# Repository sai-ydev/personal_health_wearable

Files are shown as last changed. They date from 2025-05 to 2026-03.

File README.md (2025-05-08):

# Wearable for Personal Health Monitoring
 
This is the repository for the Personal Health Monitoring Wearable. 

wearable

Here is the folder structure:
- **nRF54L15 Design Files** contains design files based on the nRF54L15 SoC. This couldn't be executed because of lack of availability.
- **BL54L15 Design Files** contains design files based on the BL54L15 module from [Ezurio](https://www.ezurio.com/product/bl54l15-series-bluetooth-le-80215-4-nfc).

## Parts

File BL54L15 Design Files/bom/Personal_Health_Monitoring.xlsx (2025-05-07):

Comment | Designator | Footprint | LCSC Part #
0 | R5 R6 R26 | RESC0603X28N | C106227
0.1uF | C1 C2 C4 C5 C7 C8 C17 C21 C23 C24 C25 C28 C31 C32 C35 C38 C42 C43 | CAPC0603X33N | C66938
1.0uF | C9 C10 C18 C19 C30 C37 | CAPC0603X33N | C76929
1.4K | R8 | RESC0603X28N | C320696
1K | R19 R21 | RESC0603X28N | C138165
2.2K | R10 R11 | RESC0603X28N | C320759
2.2nH | L1 | INDC1608X100N | C113061
2.2uF | C14 | CAPC0603X33N | C318539
2.2uH | L2 L3 | INDC2016X100N | C86093
3.9K | R18 R20 | RESC0603X28N | C171965
4.7K | R9 | RESC0603X28N | C138135
4.7UF | C20 | CAPC0603X33N | C335103
5.1K | R12 R13 | RESC0603X28N | C274341
10K | R4 R7 R14 | RESC0603X28N | C144833
10uF | C3 C11 C12 C13 C15 C16 C27 C29 C33 C36 C39 C22 | 402 | C15525
27K | R22 R23 | RESC0603X28N | C273283
32.768kHz | Y3 | CRYSTAL-SMD-3.2X1.5MM | C48615
47K | R3 | RESC0603X28N | C138097
100 | R1 | RESC0603X28N | C106229
100K | R16 R17 | RESC0603X28N | C106224
100UF | C26 | CAPC2012X145N | C141660
150 | R15 | RESC0603X28N | C319851
453-00001R | U3 | XCVR_453-00001R | C9900177187
470K | R2 | RESC0603X28N | C138098
470nF | C40 C41 | CAPC0603X33N | C85926
BLUE | D2 | LED-0603 | C94740
DNP | R24 R25 | RESC0603X28N | DNP
Debug Connector | J1 | 2X5-SMD-UNSHROUDED_DNP_NO_PASTE | C448647
EAST1616RGYA0 | LED1 | EAST1616RGYA0 | C19171339
EYESPI | X1 | ADAFRUIT_DISPLAY_EYE_SPI_DISPLAY_BOTCONTACT | C2856802
ICS-43434 | MK1 | MIC_ICS-43434 | C5656610
INTERFACE-CP2102-GMR(QFN28) | U7 | QFN28G_0.5-5X5MM | C6568
JS202011JCQN | S1 | SW_JS202011JCQN | C221665
KMR221GLFS | S2 | TACTILE_SWITCH_SMD_4.6X2.8MM | C72443
LMV358MUTAG | U2 | SON40P180X120X55-8N | C891366
LSM6DS3TR-C | U6 | LGA-14-2.5X3MM | C967633
MAX30102EFD+T | U4 | XDCR_MAX30101EFD+ | C6454833
MLX90632SLD-BCB-000-SP | U5 | XDCR_MLX90632SLD-BCB-000-SP | C7541116
NPM1300-QEAA-R | IC1 | QFN50P500X500X90-33N | C7501206
Qwiic Right Angle | J5 | JST04_1MM_RA | C160404
RV-3028-C7 | U1 | IC_RV-3028-C7-32.768KHZ-1PPM-TA-QC | C3019759
TEST-POINT3 | -0.4V -3.3V 1.2VREF 1.8V 1.8V_SW 3.3V 3.3V_SW ADC1 ADC2 VSYS V_BATT V_USB | PAD.03X.03 | DNP
TLR377GYZ-E2 | IC2 IC3 IC4 IC5 | BGA6C30P3X2_88X58X33 | C25814939
TPS60403DBVR | U10 | SOT95P280X145-5N | C11338
TYPE-C-31-M-12 | J2 | HRO_TYPE-C-31-M-12 | C165948
WA-SMSI_9774XXX243_9774045243R | MP1 MP2 MP3 MP4 | WA-SMSI_9774045243 | C9900153365

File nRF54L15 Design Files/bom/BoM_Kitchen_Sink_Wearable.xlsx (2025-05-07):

Part | Price
Glucometer Test Strip Connector | 0.13
Bluetooth Module | 3.99
LSM6DS3TR IMU | 3.82
Microphone | 3.12
MAX30102 Heart Rate/SPO2 sensor | 13.39
MLX90632 Temperature Sensor | 13.75
1.47" Display | 17.5

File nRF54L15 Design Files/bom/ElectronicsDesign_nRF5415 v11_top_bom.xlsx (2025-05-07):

Comment | Designator | Footprint | LCSC Part #
0 | R5 R6 R26 | RESC0603X28N | C106227
0.1uF | C1 C2 C4 C5 C7 C8 C17 C18 C21 C23 C24 C25 C28 C31 C32 C34 C35 C37 C38 C43 | CAPC0603X33N | C66938
0.3pF | C48 | CAPC0603X33N | C76927
0.5pF | C47 | CAPC0603X33N | C161292
1.0UF | C9 C10 C19 C30 | CAPC0603X33N | C76929
1.4K | R8 | RESC0603X28N | C320696
1.5pF | C50 | CAPC0603X33N | C85897
1K | R19 R21 R24 | RESC0603X28N | C138165
1nH | L5 L6 | INDC0603X33N | C86099
2.0pF | C49 | CAPC0603X33N | C88875
2.2K | R10 R11 | RESC0603X28N | C320759
2.2nH | L1 | INDC1608X100N | C113061
2.2uF | C14 C42 C44 | CAPC0603X33N | C318539
2.2uH | L2 L3 | INDC2016X100N | C86093
2.7nH | L7 | INDC0603X33N | C86109
3.5nH | L8 L9 | INDC0603X33N | C206424
3.9K | R18 R20 | RESC0603X28N | C171965
3.9pF | C6 | CAPC0603X33N | C76926
4.7K | R9 | RESC0603X28N | C138135
4.7UF | C20 | CAPC0603X33N | C335103
5.1K | R12 R13 | RESC0603X28N | C274341
10K | R4 R7 R14 | RESC0603X28N | C144833
10nF | C45 C46 | CAPC0603X33N | C85930
10uF | C3 C11 C12 C13 C15 C16 C22 C27 C29 C33 C36 C39 | 0402-TIGHT | C15525
27K | R22 R23 | RESC0603X28N | C158653
47K | R3 | RESC0603X28N | C138097
100 | R1 | RESC0603X28N | C106229
100K | R16 R17 | RESC0603X28N | C106224
100UF | C26 | CAPC2012X145N | C141660
120O | FB1 | BEADC0603X33N | C88958
150 | R15 | RESC0603X28N | C319851
470K | R2 | RESC0603X28N | C138098
470nF | C40 C41 | CAPC0603X33N | C85926
BLUE | D2 | LED-0603 | C94740
Debug Connector | J1 | 2X5-SMD-UNSHROUDED_DNP_NO_PASTE | C448647
EAST1616RGYA0 | LED1 | EAST1616RGYA0 | C19171339
ECS-320-CDX-2291 | Y1 | XTAL_ECS-320-CDX-2291 | C187794
EYESPI | X1 | ADAFRUIT_DISPLAY_EYE_SPI_DISPLAY_BOTCONTACT | C2856802
INTERFACE-CP2102-GMR(QFN28) | U7 | QFN28G_0.5-5X5MM | C6568
JS202011JCQN | S1 | SW_JS202011JCQN | C221665
KMR221GLFS | S2 | TACTILE_SWITCH_SMD_4.6X2.8MM | C72443
LMV358MUTAG | U2 | SON40P180X120X55-8N | C891366
LQM18PN4R7MFRL | L4 | INDC1608X95N | LQM18PN4R7MFRL
LSM6DS3TR-C | U6 | LGA-14-2.5X3MM | C967633
MAX30102EFD+T | U4 | XDCR_MAX30101EFD+ | C6454833
MLX90632SLD-BCB-000-SP | U5 | XDCR_MLX90632SLD-BCB-000-SP | C7541116
NPM1300-QEAA-R | IC1 | QFN50P500X500X90-33N | C7501206
NRF54L15-QFAA-R | U8 | QFN40P600X600X90-49N | C42458750
Qwiic Right Angle | J5 | JST04_1MM_RA | C160404
RV-3028-C7 | U1 | IC_RV-3028-C7-32.768KHZ-1PPM-TA-QC | C3019759
TEST-POINT3 | -0.4V -3.3V 1.2VREF 1.8V 3.3V ADC1 ADC2 VSYS V_BATT V_USB | PAD.03X.03 | DNP
TLR377GYZ-E2 | IC2 IC3 IC4 IC5 | BGA6C30P3X2_88X58X33 | C25814939
TPS60403DBVR | U10 | SOT95P280X145-5N | C11338
TYPE-C-31-M-12 | J2 | HRO_TYPE-C-31-M-12 | C165948
WA-SMSI_9774XXX243_9774045243R | MP1 MP2 MP3 MP4 | WA-SMSI_9774045243 | C9900153365
YC0009AA | E1 | XCVR_YC0009AA | C3292972

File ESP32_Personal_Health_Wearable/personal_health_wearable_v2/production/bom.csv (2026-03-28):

Designator | Footprint | Quantity | Value | LCSC Part #
C1 | 0402 | 1 | 22uF | C105226
C10, C11, C12, C13, C2, C25, C3, C4, C5, C6 | 0402 | 10 | 0.1uF | C1525
C14, C15, C16, C17, C18, C19, C20, C21, C22, C23, C24, C26, C29, C31, C33 | 0402 | 15 | 1.0uF | C361059
C27, C28 | 0402 | 2 | 2.2uF | C159814
C30, C7, C8, C9 | 0402 | 4 | 10uF | C15525
C32 | 0402 | 1 | 470nF | C47339
CN1 | FPC-SMD_30P-P0.50_FH12A-30S-0.5SH | 1 | ~ | C3036214
D1 | 0402 | 1 | Red | C74341
D2 | D_SOD-523 | 1 | 350mA | C154768
J1 | HRO_TYPE-C-31-M-12 | 1 | TYPE-C-31-M-12 | C165948
J4 | JST_1x02_P2.0mm_Horizontal_SMD | 1 | JST_2mm_LiPo | C295747
L1 | 0402 | 1 | 2.2nH | C27122
L2 | IND_LQH3NPN2R2MJRL | 1 | LQH3NPN2R2MJRL | C341775
R1, R13, R14, R2 | 0402 | 4 | 10k | C25531
R10 | 0402 | 1 | 0 | C17168
R11 | 0402 | 1 | 1.1K | C25860
R12 | 0402 | 1 | 590 | C159007
R15 | 0402 | 1 | 0.01 | C346478
R3, R6 | 0402 | 2 | 100 | C25076
R4, R5 | 0402 | 2 | 5.1k | C25905
SW1, SW2 | Push_SMD_4.6x2.8mm_h1.9mm | 2 | SMD_4.6x2.8mm_h1.9mm | C99271
U1 | ESP32-C6-MINI-1 | 1 | ESP32-C6-MINI-1 | C5736265
U3 | Texas_DRC0010J_ThermalVias | 1 | TPS63001 | C28060
U4, U6 | SON50P400X400X80-15N | 2 | LMP91000SDE_NOPB | C181364
U5 | TSSOP-10_3x3mm_P0.5mm | 1 | ADS1114IDGS | C174291
U7 | VQFN-16-1EP_3x3mm_P0.5mm_EP1.6x1.6mm | 1 | BQ24075RGT | C15464
U8 | Texas_S-PDSO-N12 | 1 | BQ27441DRZR-G1A | C473397

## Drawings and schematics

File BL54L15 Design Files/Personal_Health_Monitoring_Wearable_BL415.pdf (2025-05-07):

A

1 | 2 | 3 | 4 | 5 | 6 | 7 | 8

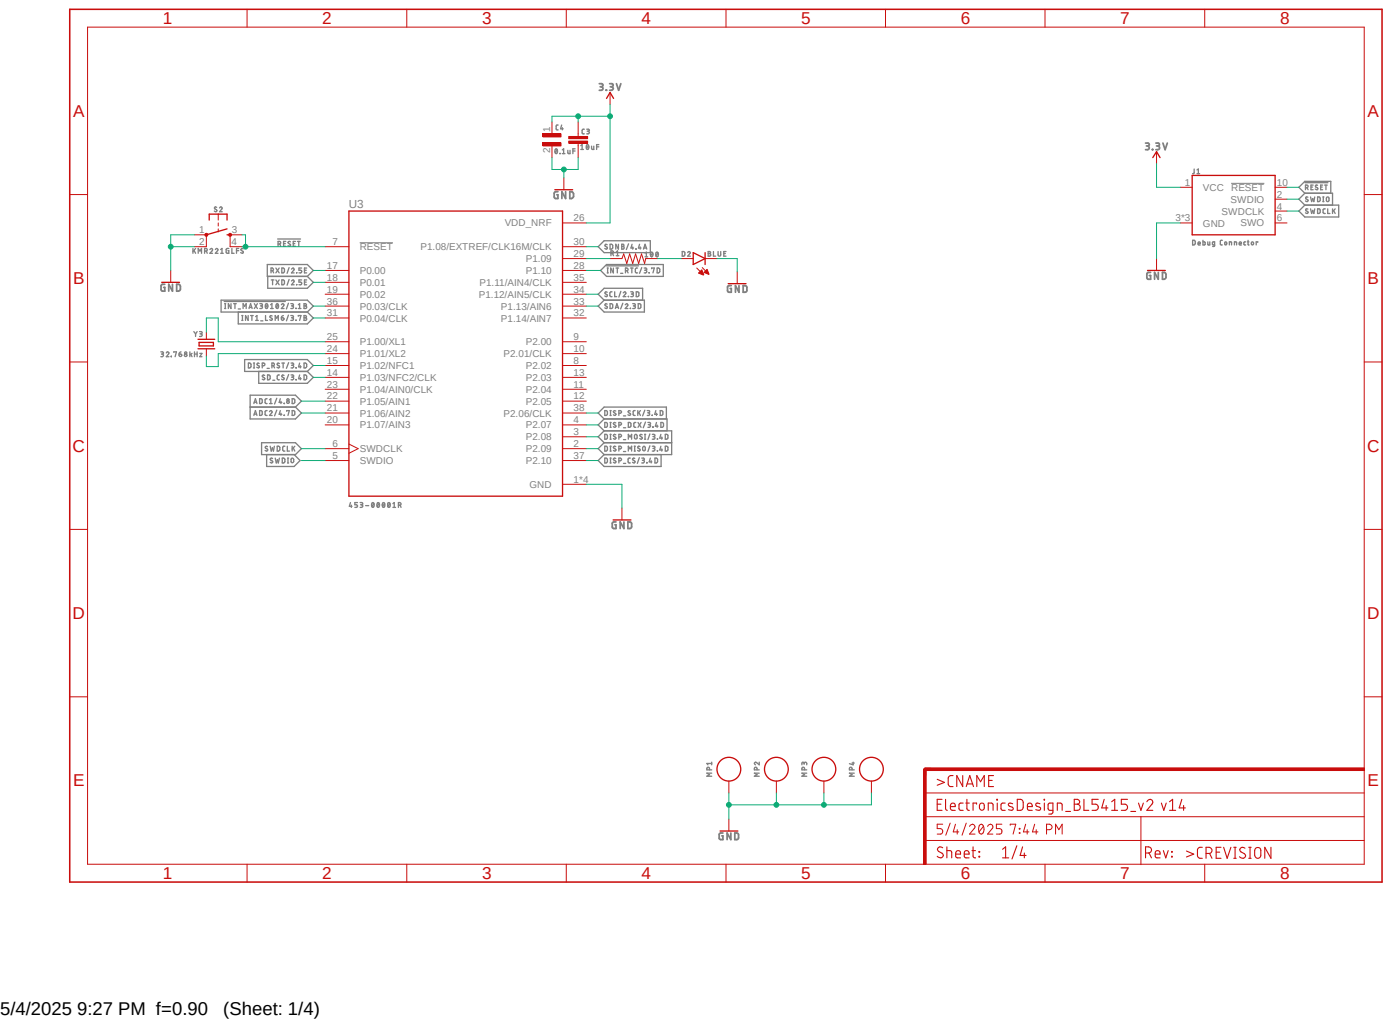
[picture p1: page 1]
5/4/2025 9:27 PM f=0.90 (Sheet: 1/4); VCC 1; GND 3*3; RESET; 10 SWO; 6 SWDCLK; 4 SWDIO; VDD_NRF; 26 SWDIO 5; SWDCLK 6; RESET 7; GND; 1*4 P2.01/CLK; 12 P2.06/CLK; P1.02/NFC1 15; P1.03/NFC2/CLK 14; P1.04/AIN0/CLK 23; P1.05/AIN1 22; P1.06/AIN2 21; P1.07/AIN3 20; P1.08/EXTREF/CLK16M/CLK; P0.03/CLK 36; P0.04/CLK 31; P1.14/AIN7; 32 P1.13/AIN6; 33 P1.12/AIN5/CLK; 34 P1.11/AIN4/CLK

A

A

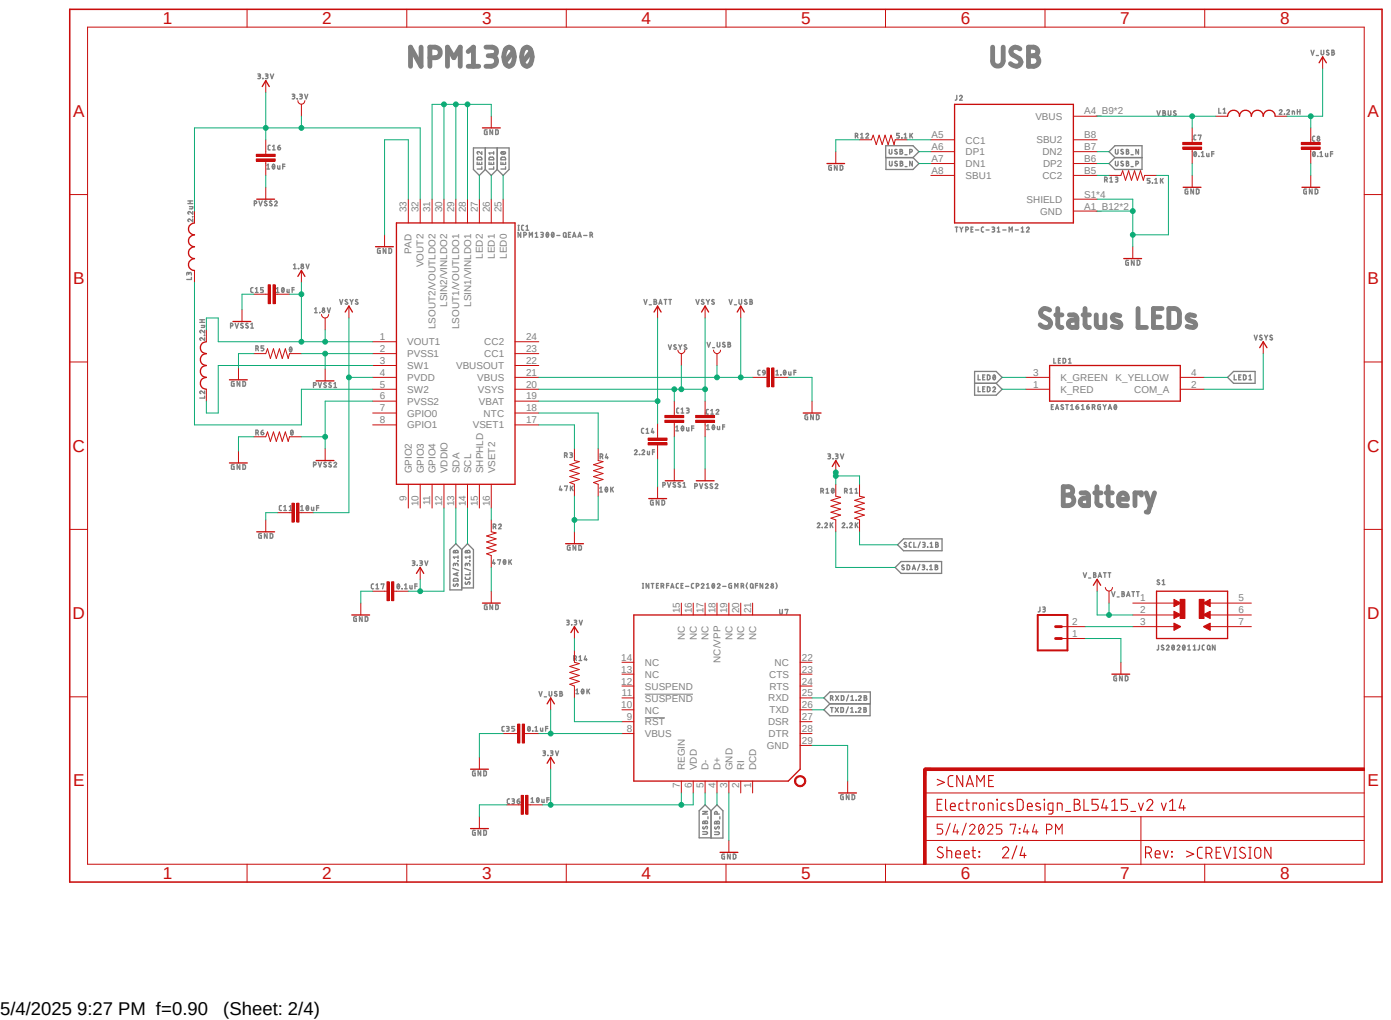
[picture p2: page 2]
5/4/2025 9:27 PM f=0.90 (Sheet: 2/4); VOUT1 1; PVSS1 2; PVDD 4; PVSS2 6; GPIO0 7; GPIO1 8; GPIO²; SBU1 A8; SHIELD; S1*4 GND; A1_B12*2 VBUS; B5 SBU2; B7 K_RED 1; COM_A; 2 K_GREEN 3; K_YELLOW; 7 DCD; 1 RI 2 GND; 4 D- 5 VDD; 6 REGIN

9 GPIO3 10 GPIO4 11 VDDIO 12 SDA 13 SCL 14 SHPHLD 15 VSET2 16 CC2 24 CC1 23 VBUSOUT 22 VBUS 21 VSYS 20 VBAT 19 NTC 18 VSET1 17 PAD 33 VOUT2 32 LSOUT2/VOUTLDO2 31 LSIN2/VINLDO2 30 LSOUT1/VOUTLDO1 29 LSIN1/VINLDO1 28 LED2 27 LED1 26 LED0 25

7 VBUS 8 RST 9 NC 10 SUSPEND 11 SUSPEND 12 NC 13 NC 14 NC 15 NC 16 NC 17 NC/VPP 18 NC 19 NC 20 NC 21 NC 22 CTS 23 RTS 24 RXD 25 TXD 26 DSR 27 DTR 28 GND 29

A

A

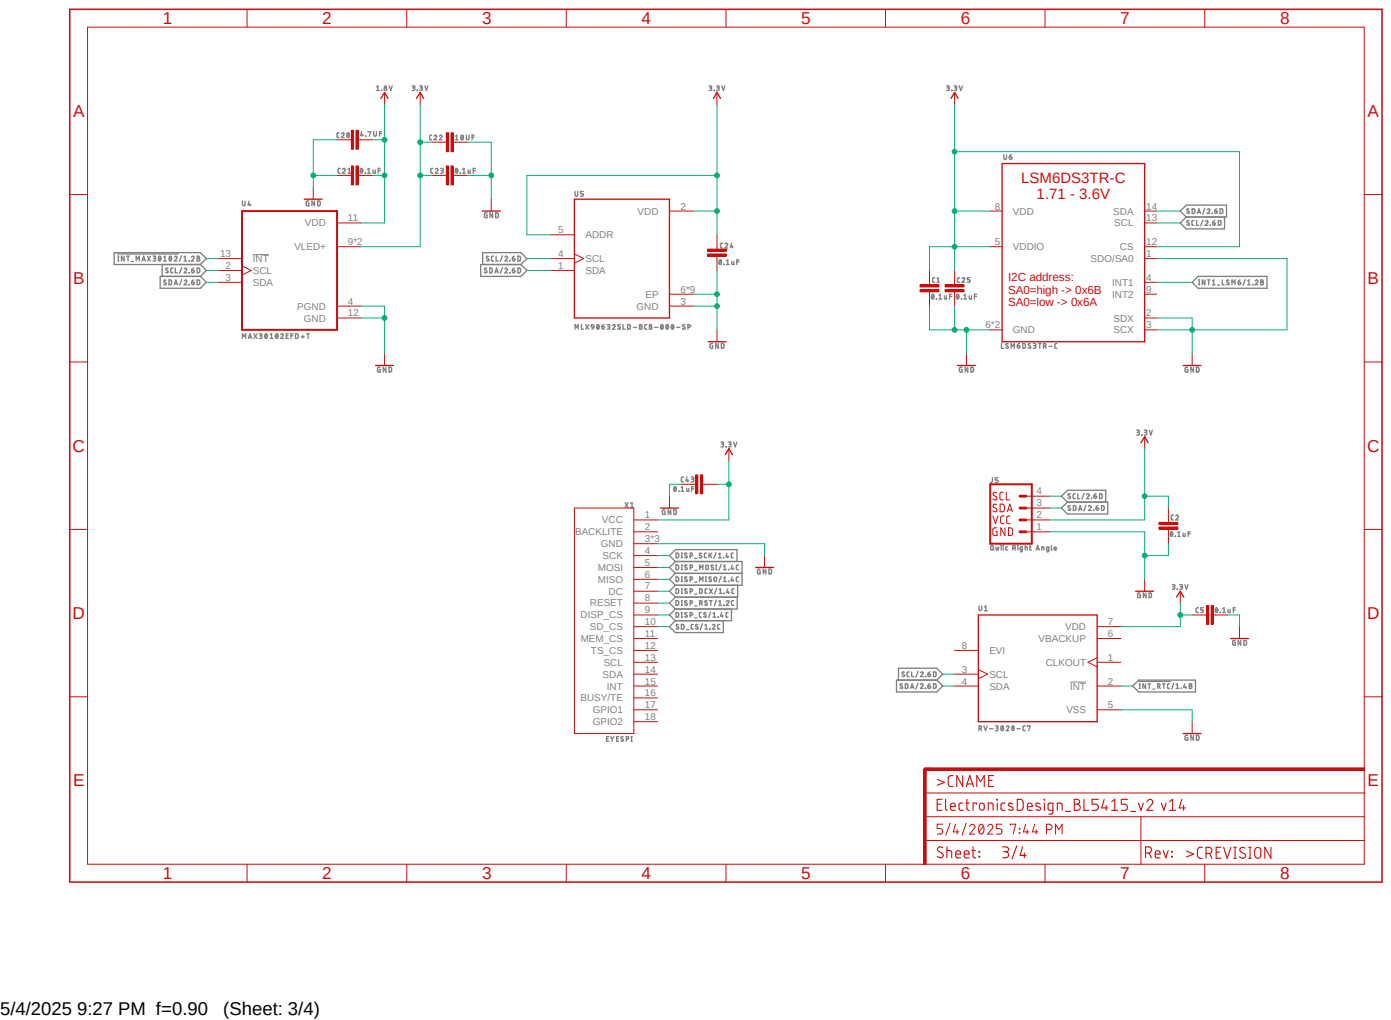
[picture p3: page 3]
5/4/2025 9:27 PM f=0.90 (Sheet: 3/4); INT 13; SCL 2; SDA 3; VDD; 11 VLED+; 9*2 PGND; 4 GND; SDA 1; 2 GND; 3 SCL 4; ADDR 5; VDD 8; VDDIO 5; INT1; INT2; 9 GND 6*2; SDA; 14 SDO/SA0; 12 SCL; 13 SDX; 2 SCX; 3 BACKLITE; 2 BUSY/TE; 7 DISP_CS; 9 GND; 3*3 GPIO1; 17 GPIO2; INT; 15 MEM_CS; 11 MISO; 6 MOSI; 5 RESET; 8 SCK; 4 SCL; 13 SDA; 12 VCC; 7 VSS; 5 CLKOUT; 2 EVI 8; SCL 3; SDA 4; VBACKUP; LSM6DS3TR-C 1.71 - 3.6V; I2C address: SA0=high -> 0x6B SA0=low -> 0x6A

A

1 | 2 | 3 | 4 | 5 | 6 | 7 | 8

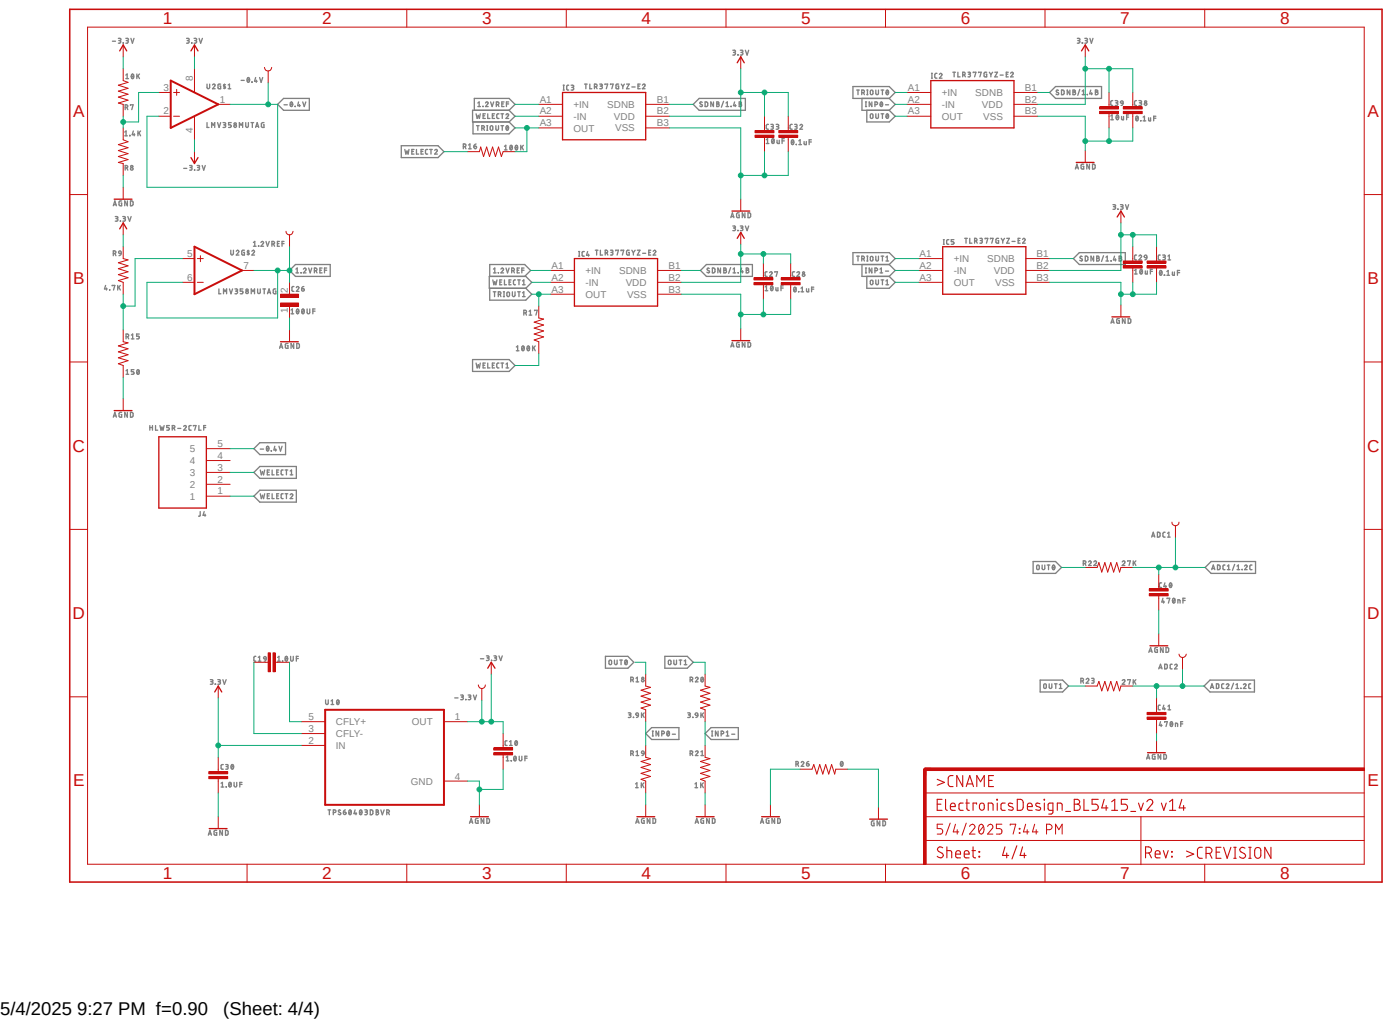
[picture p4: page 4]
5/4/2025 9:27 PM f=0.90 (Sheet: 4/4); CFLY+ 5; CFLY- 3; OUT; 1 GND; OUT A3; SDNB; B1 VDD; B2 VSS

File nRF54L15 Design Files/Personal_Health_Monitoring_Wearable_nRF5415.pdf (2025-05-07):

A

1 | 2 | 3 | 4 | 5 | 6 | 7 | 8

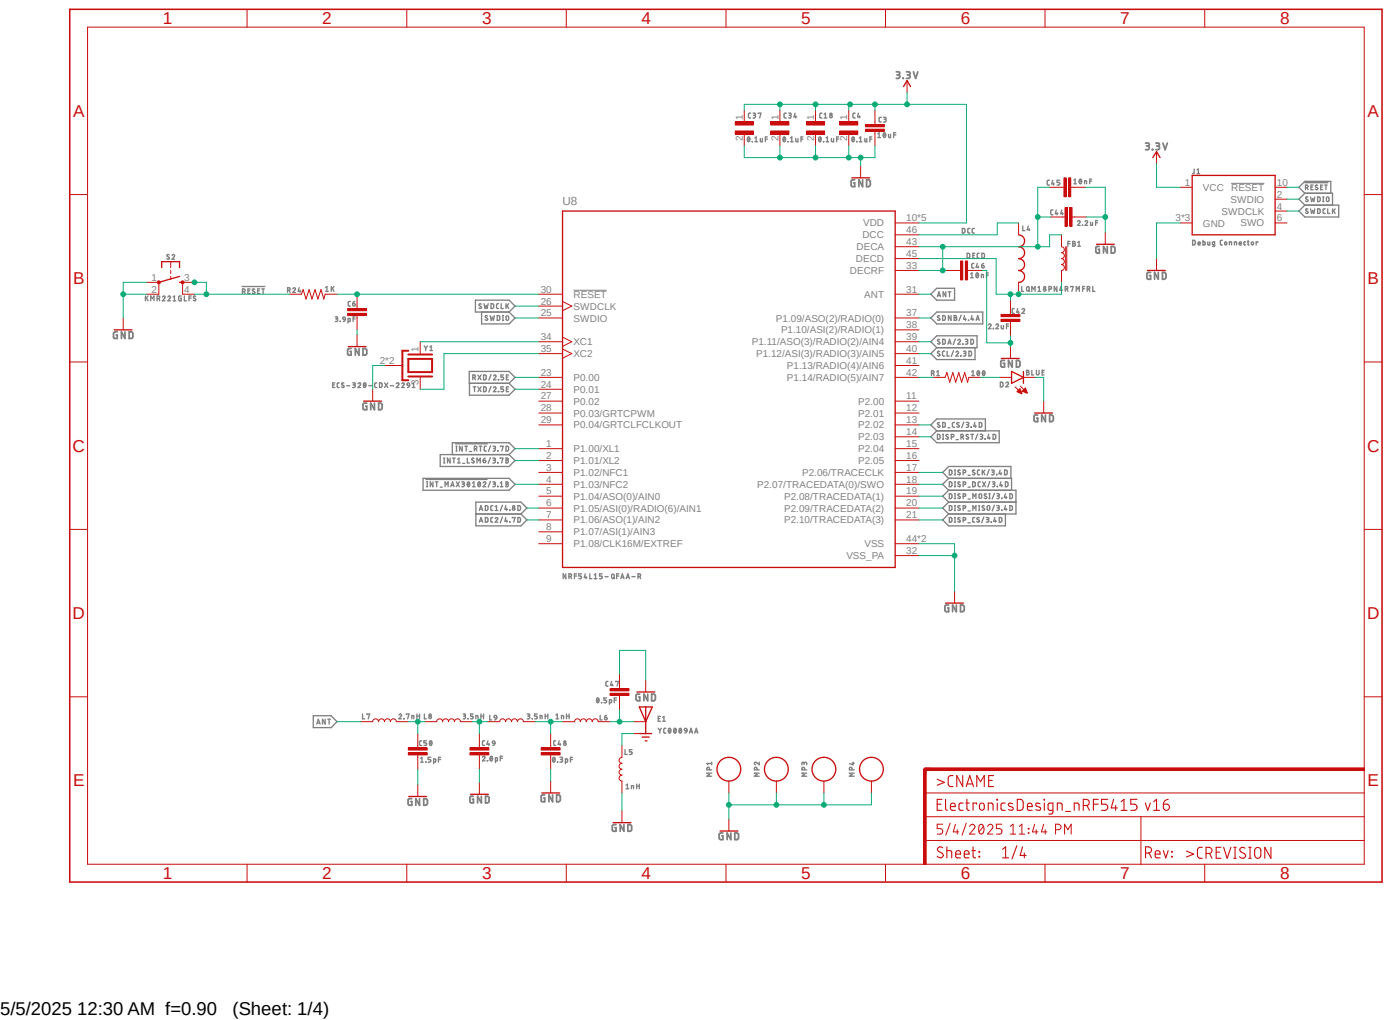
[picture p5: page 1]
5/5/2025 12:30 AM f=0.90 (Sheet: 1/4); VCC 1; GND 3*3; RESET; 10 SWO; 6 SWDCLK; 4 SWDIO; DCC; 46 DECA; 43 DECD; 45 DECRF; 33 VDD; 10*5 RESET 30; SWDCLK 26; P0.03/GRTCPWM 28; P0.04/GRTCLFCLKOUT 29; P1.02/NFC1 3; P1.03/NFC2 4; P1.04/ASO(0)/AIN0 5; P1.05/ASI(0)/RADIO(6)/AIN1 6; P1.06/ASO(1)/AIN2 7; P1.07/ASI(1)/AIN3 8; P1.08/CLK16M/EXTREF 9; P1.09/ASO(2)/RADIO(0); 37 P1.10/ASI(2)/RADIO(1); 38 ANT; 31 P1.11/ASO(3)/RADIO(2)/AIN4; 39 P1.12/ASI(3)/RADIO(3)/AIN5; 40 P1.13/RADIO(4)/AIN6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

A

A

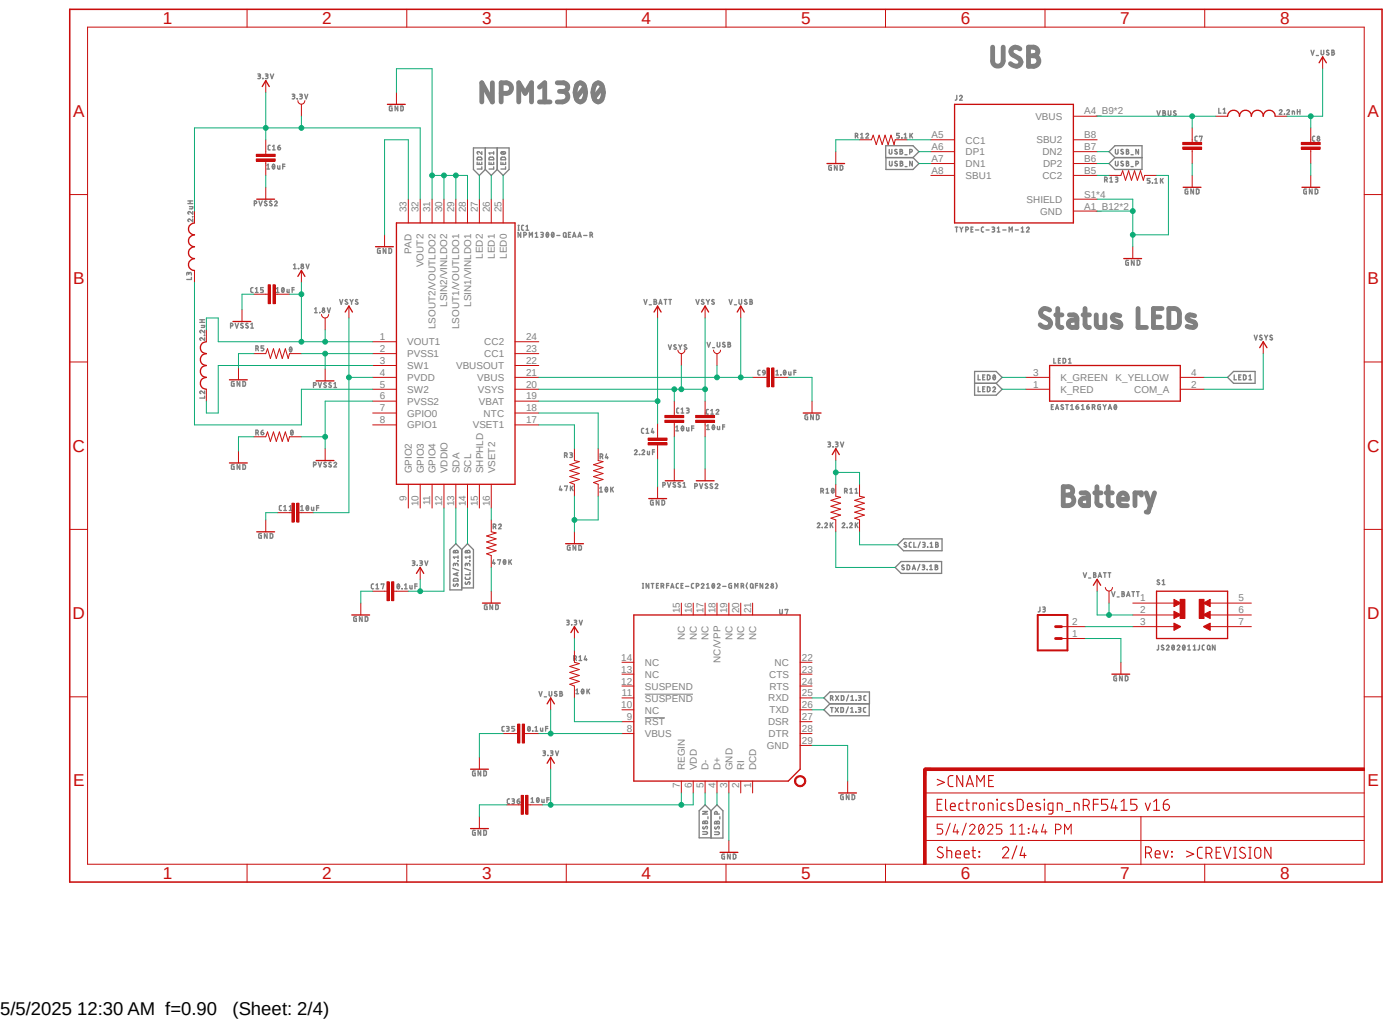
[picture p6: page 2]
5/5/2025 12:30 AM f=0.90 (Sheet: 2/4); VOUT1 1; PVSS1 2; PVDD 4; PVSS2 6; GPIO0 7; GPIO1 8; GPIO²; SBU1 A8; SHIELD; S1*4 GND; A1_B12*2 VBUS; B5 SBU2; B7 K_RED 1; COM_A; 2 K_GREEN 3; K_YELLOW; 7 DCD; 1 RI 2 GND; 4 D- 5 VDD; 6 REGIN

9 GPIO3 10 GPIO4 11 VDDIO 12 SDA 13 SCL 14 SHPHLD 15 VSET2 16 CC2 24 CC1 23 VBUSOUT 22 VBUS 21 VSYS 20 VBAT 19 NTC 18 VSET1 17 PAD 33 VOUT2 32 LSOUT2/VOUTLDO2 31 LSIN2/VINLDO2 30 LSOUT1/VOUTLDO1 29 LSIN1/VINLDO1 28 LED2 27 LED1 26 LED0 25

7 VBUS 8 RST 9 NC 10 SUSPEND 11 SUSPEND 12 NC 13 NC 14 NC 15 NC 16 NC 17 NC/VPP 18 NC 19 NC 20 NC 21 NC 22 CTS 23 RTS 24 RXD 25 TXD 26 DSR 27 DTR 28 GND 29

A

A

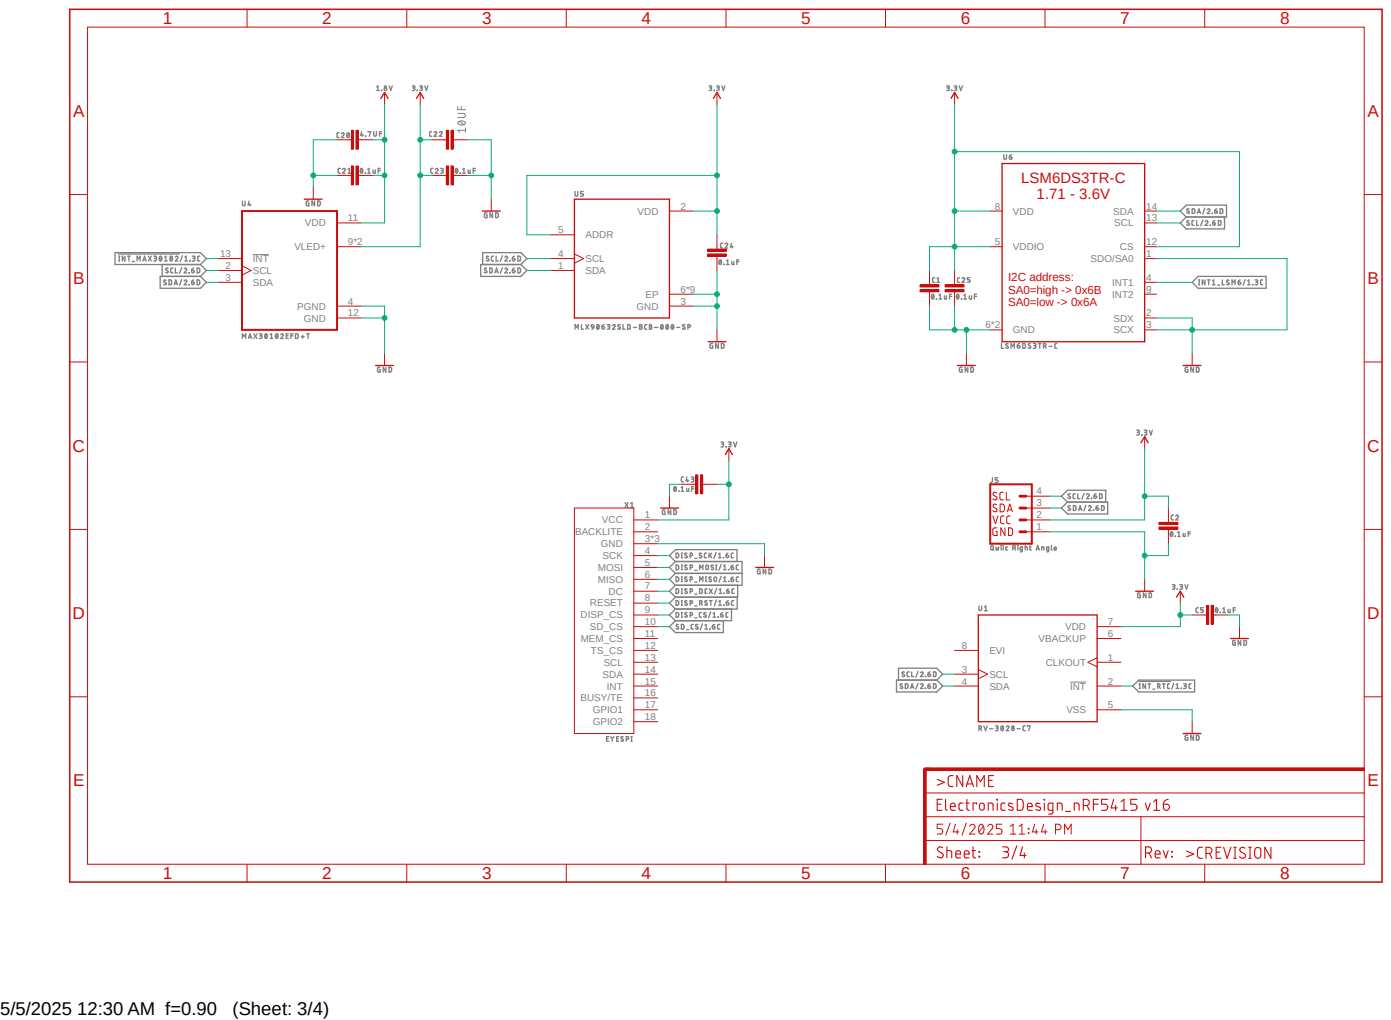
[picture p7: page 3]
5/5/2025 12:30 AM f=0.90 (Sheet: 3/4); INT 13; SCL 2; SDA 3; VDD; 11 VLED+; 9*2 PGND; 4 GND; SDA 1; 2 GND; 3 SCL 4; ADDR 5; VDD 8; VDDIO 5; INT1; INT2; 9 GND 6*2; SDA; 14 SDO/SA0; 12 SCL; 13 SDX; 2 SCX; 3 BACKLITE; 2 BUSY/TE; 7 DISP_CS; 9 GND; 3*3 GPIO1; 17 GPIO2; INT; 15 MEM_CS; 11 MISO; 6 MOSI; 5 RESET; 8 SCK; 4 SCL; 13 SDA; 12 VCC; 7 VSS; 5 CLKOUT; 2 EVI 8; SCL 3; SDA 4; VBACKUP; LSM6DS3TR-C 1.71 - 3.6V; I2C address: SA0=high -> 0x6B SA0=low -> 0x6A

A

1 | 2 | 3 | 4 | 5 | 6 | 7 | 8

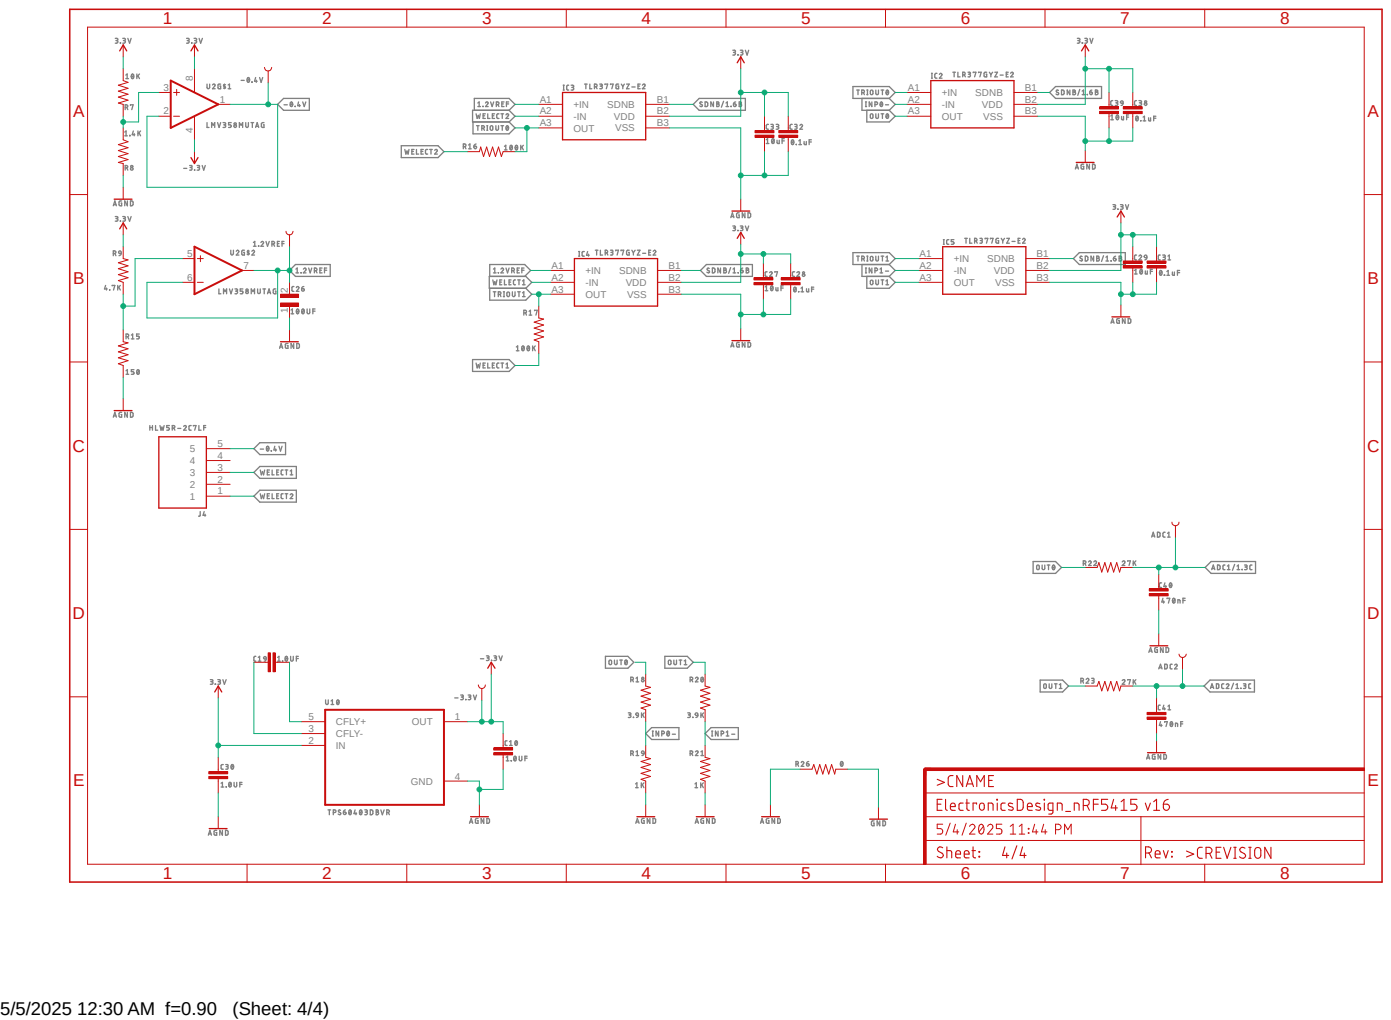
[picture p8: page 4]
5/5/2025 12:30 AM f=0.90 (Sheet: 4/4); CFLY+ 5; CFLY- 3; OUT; 1 GND; OUT A3; SDNB; B1 VDD; B2 VSS

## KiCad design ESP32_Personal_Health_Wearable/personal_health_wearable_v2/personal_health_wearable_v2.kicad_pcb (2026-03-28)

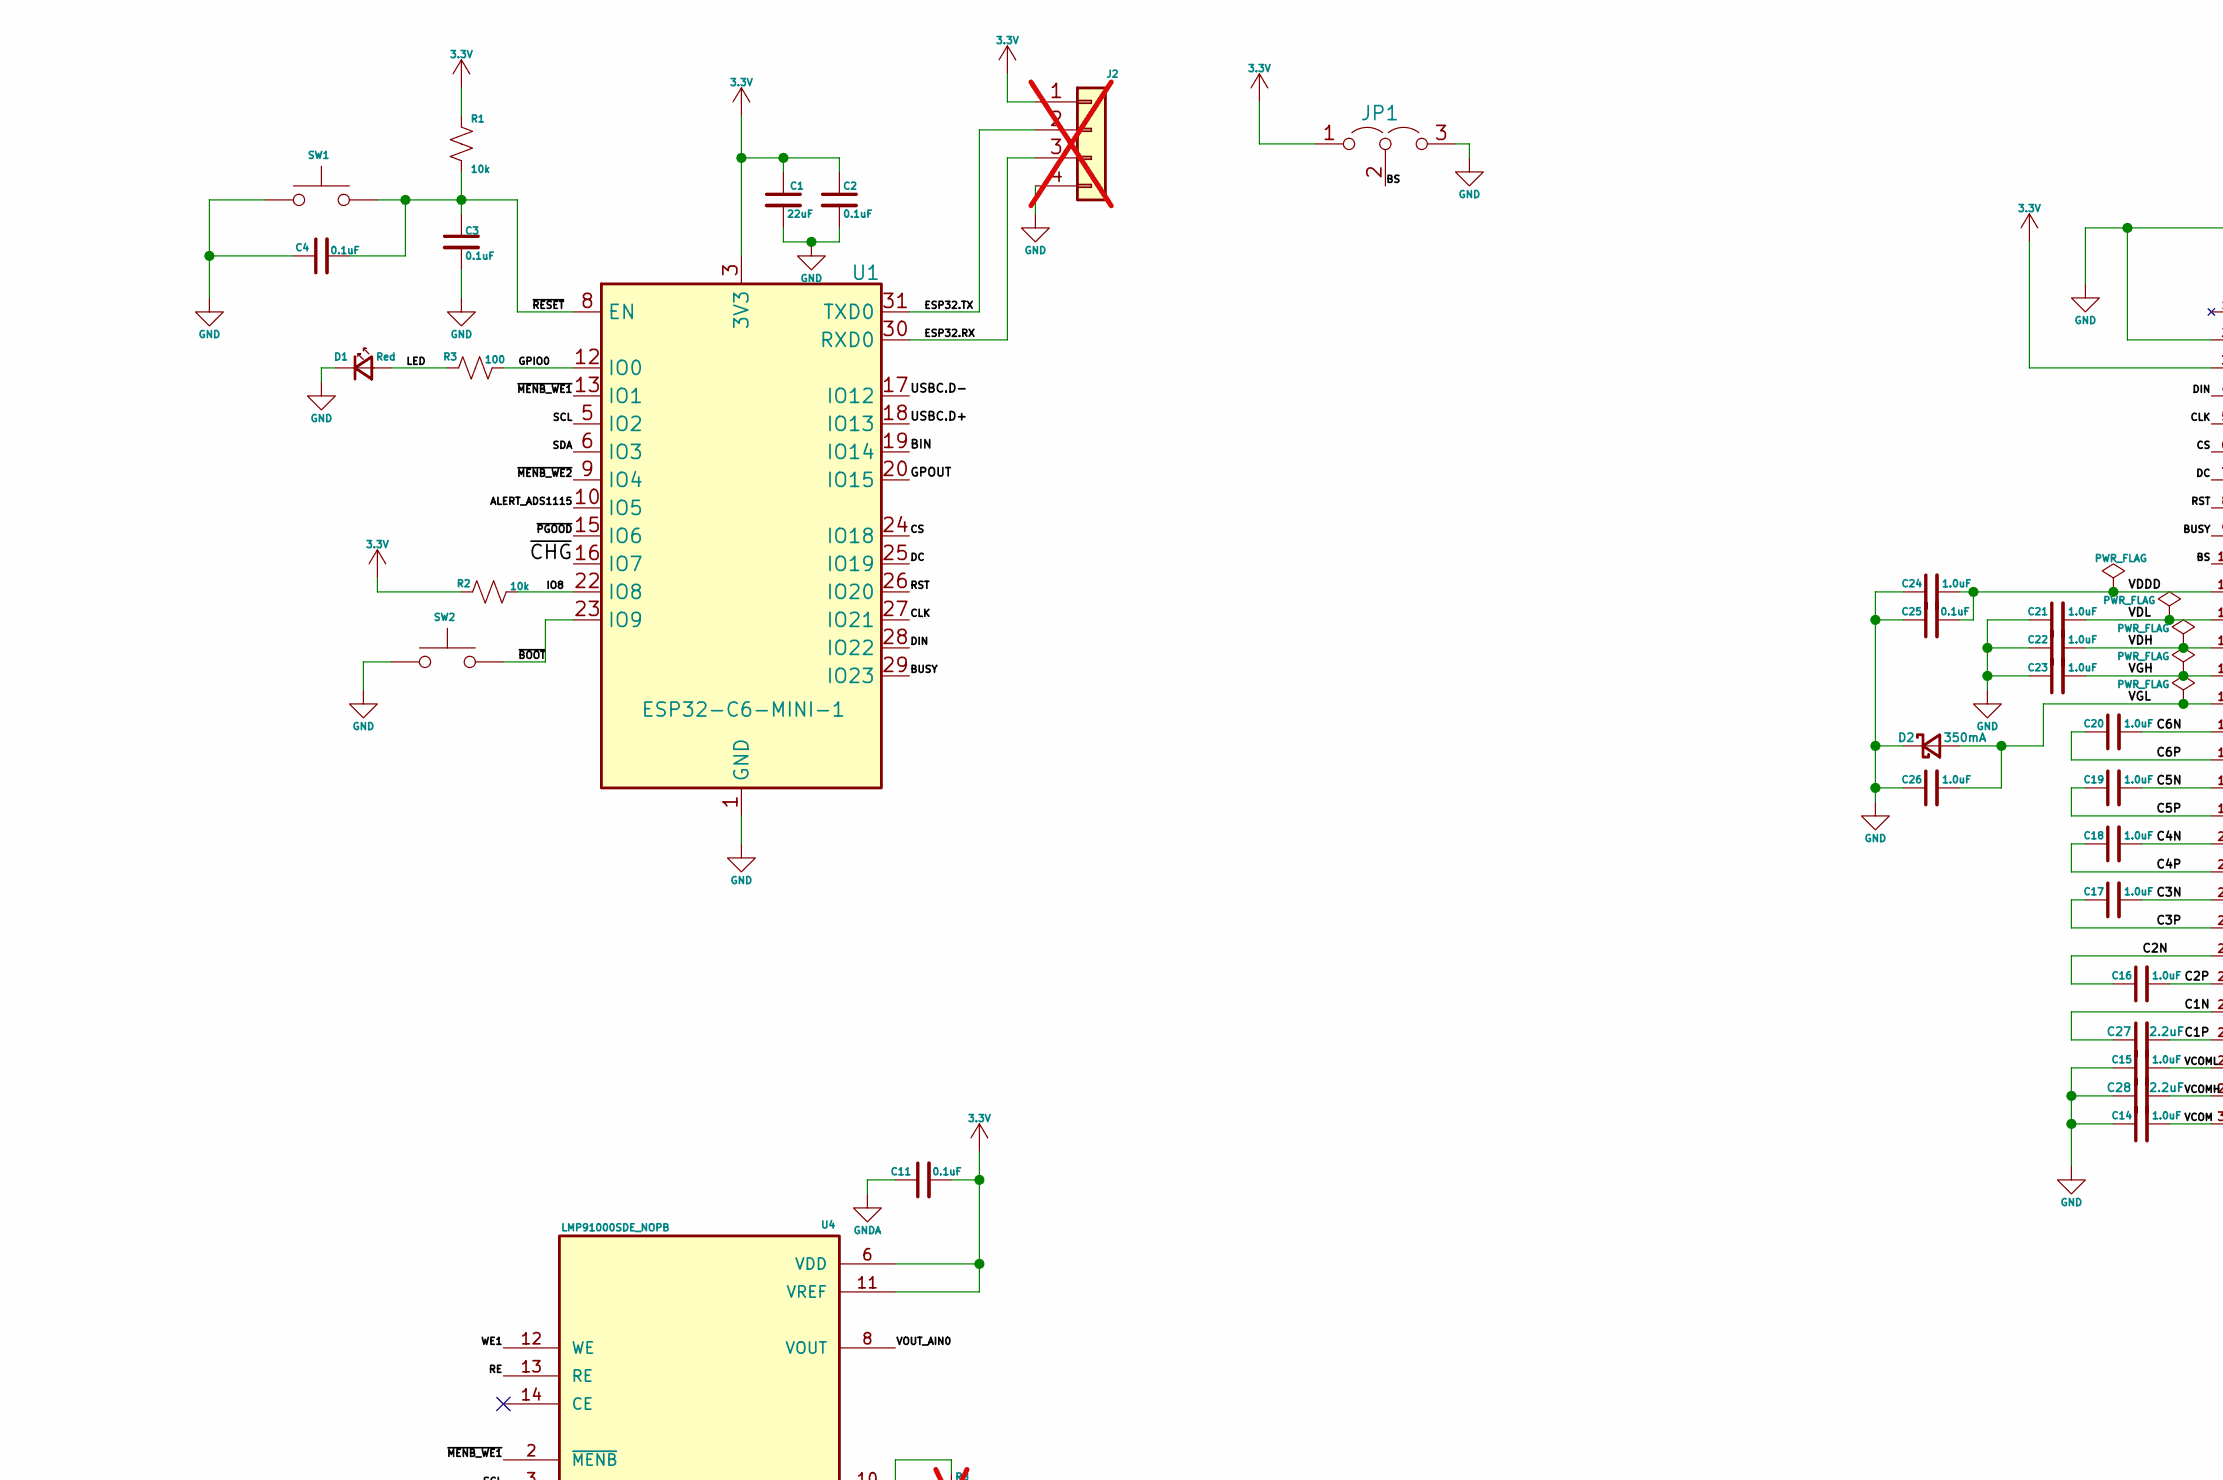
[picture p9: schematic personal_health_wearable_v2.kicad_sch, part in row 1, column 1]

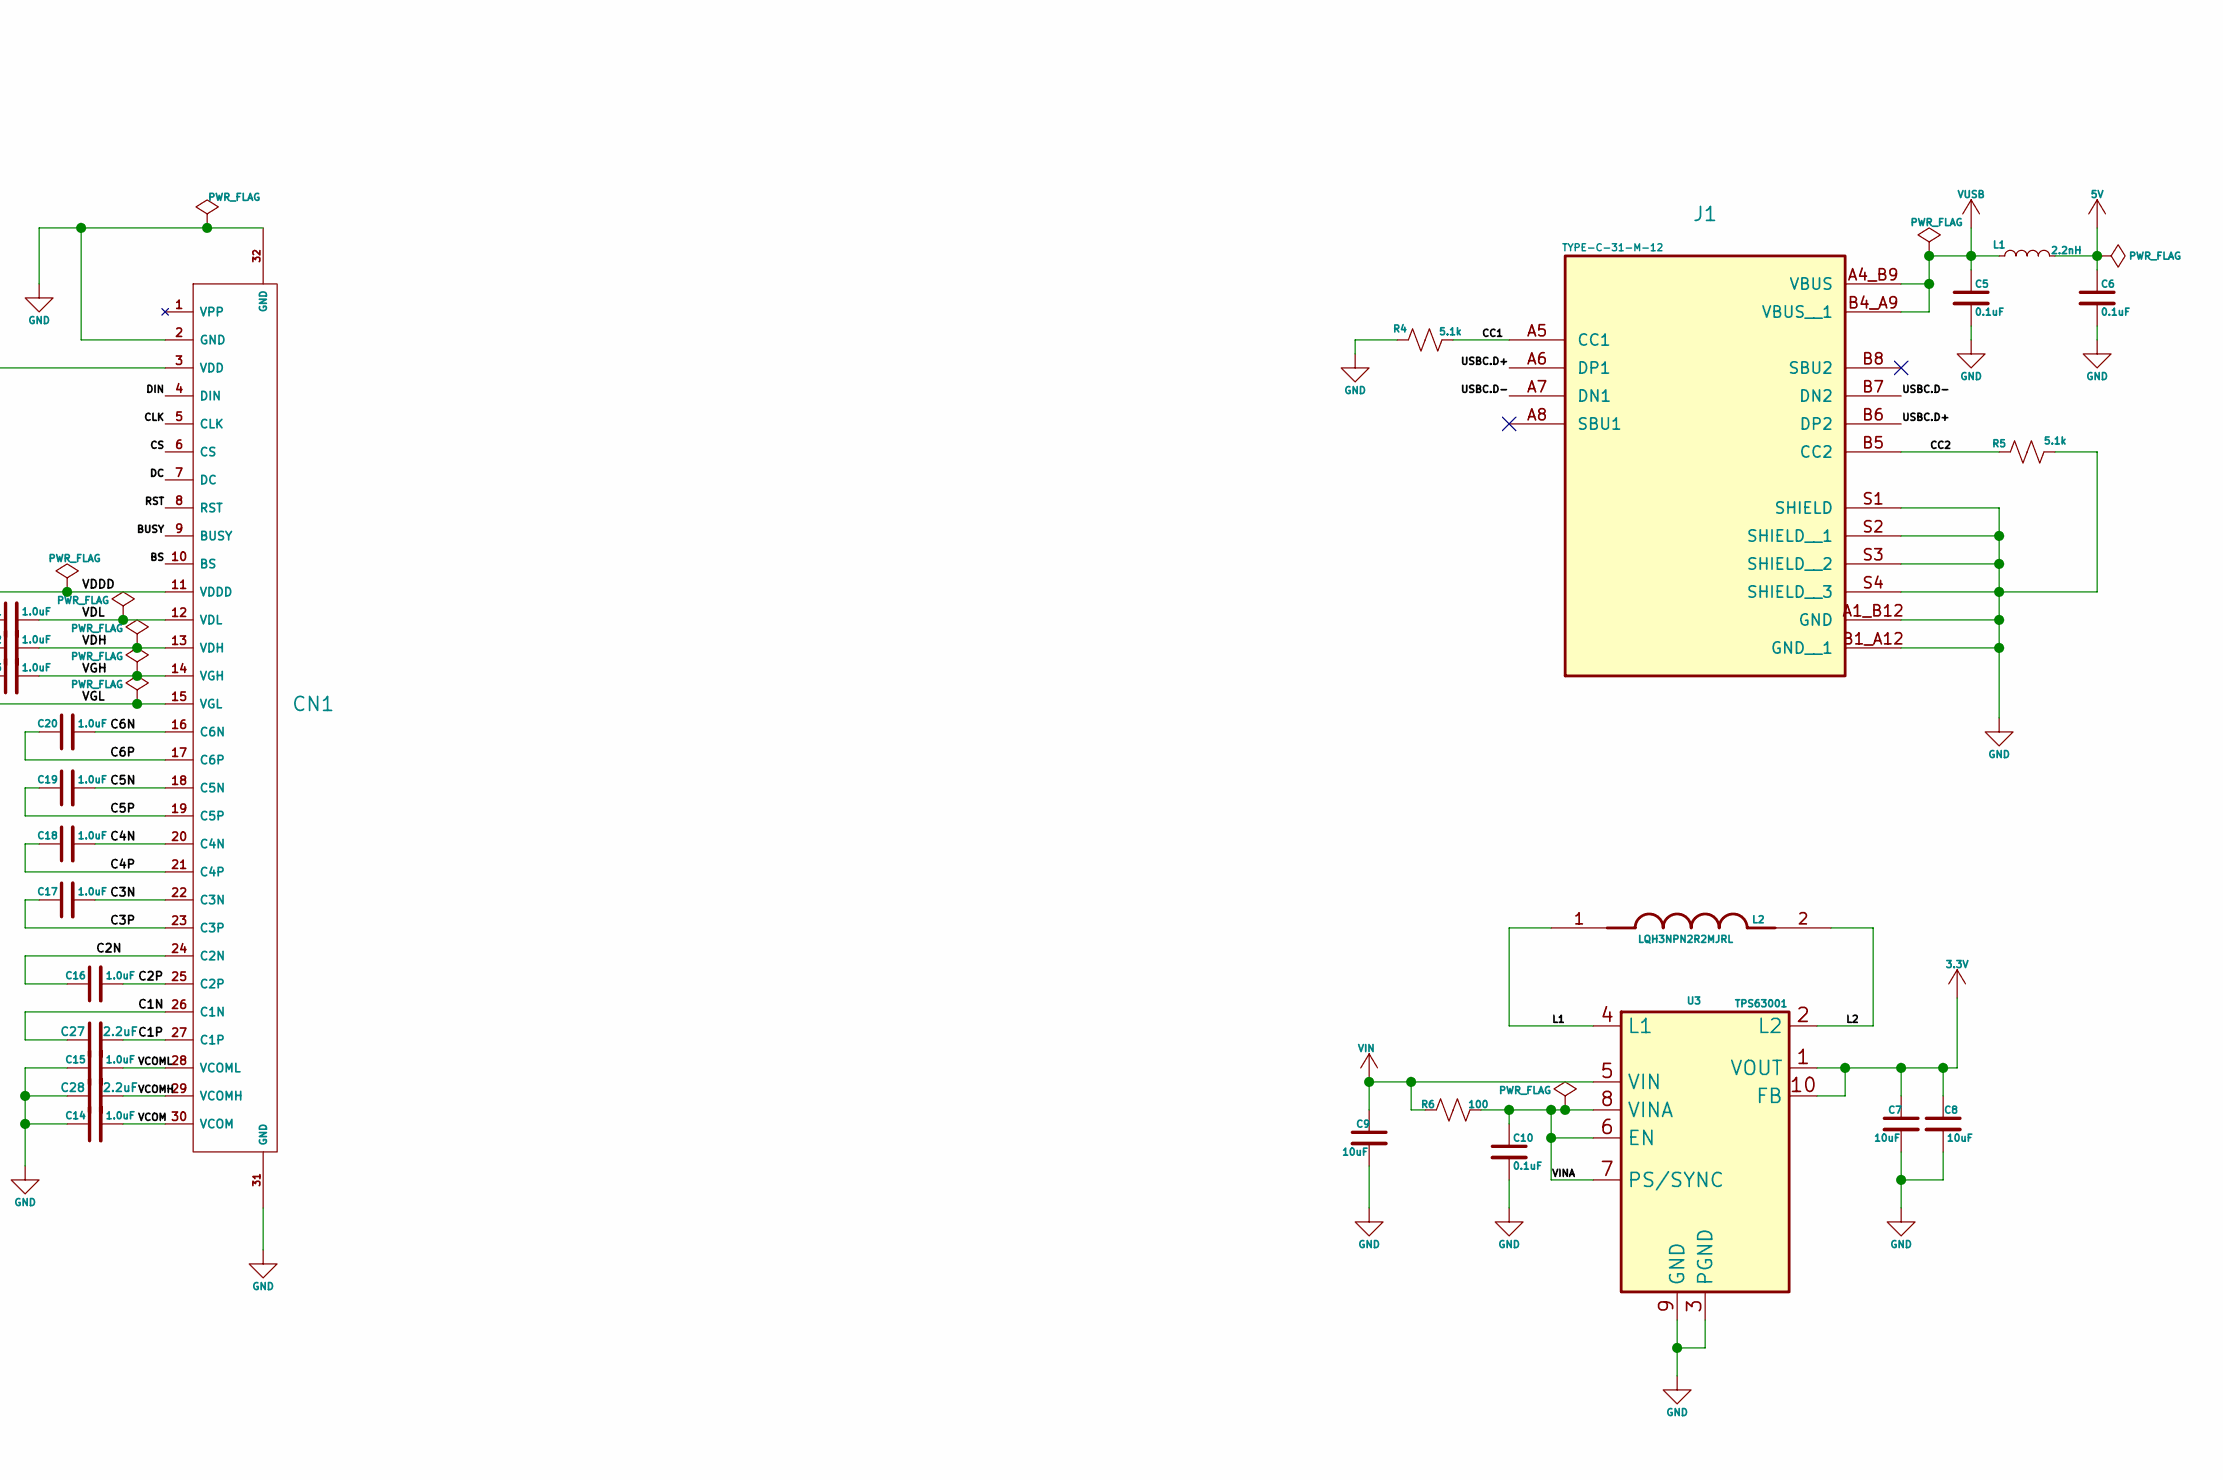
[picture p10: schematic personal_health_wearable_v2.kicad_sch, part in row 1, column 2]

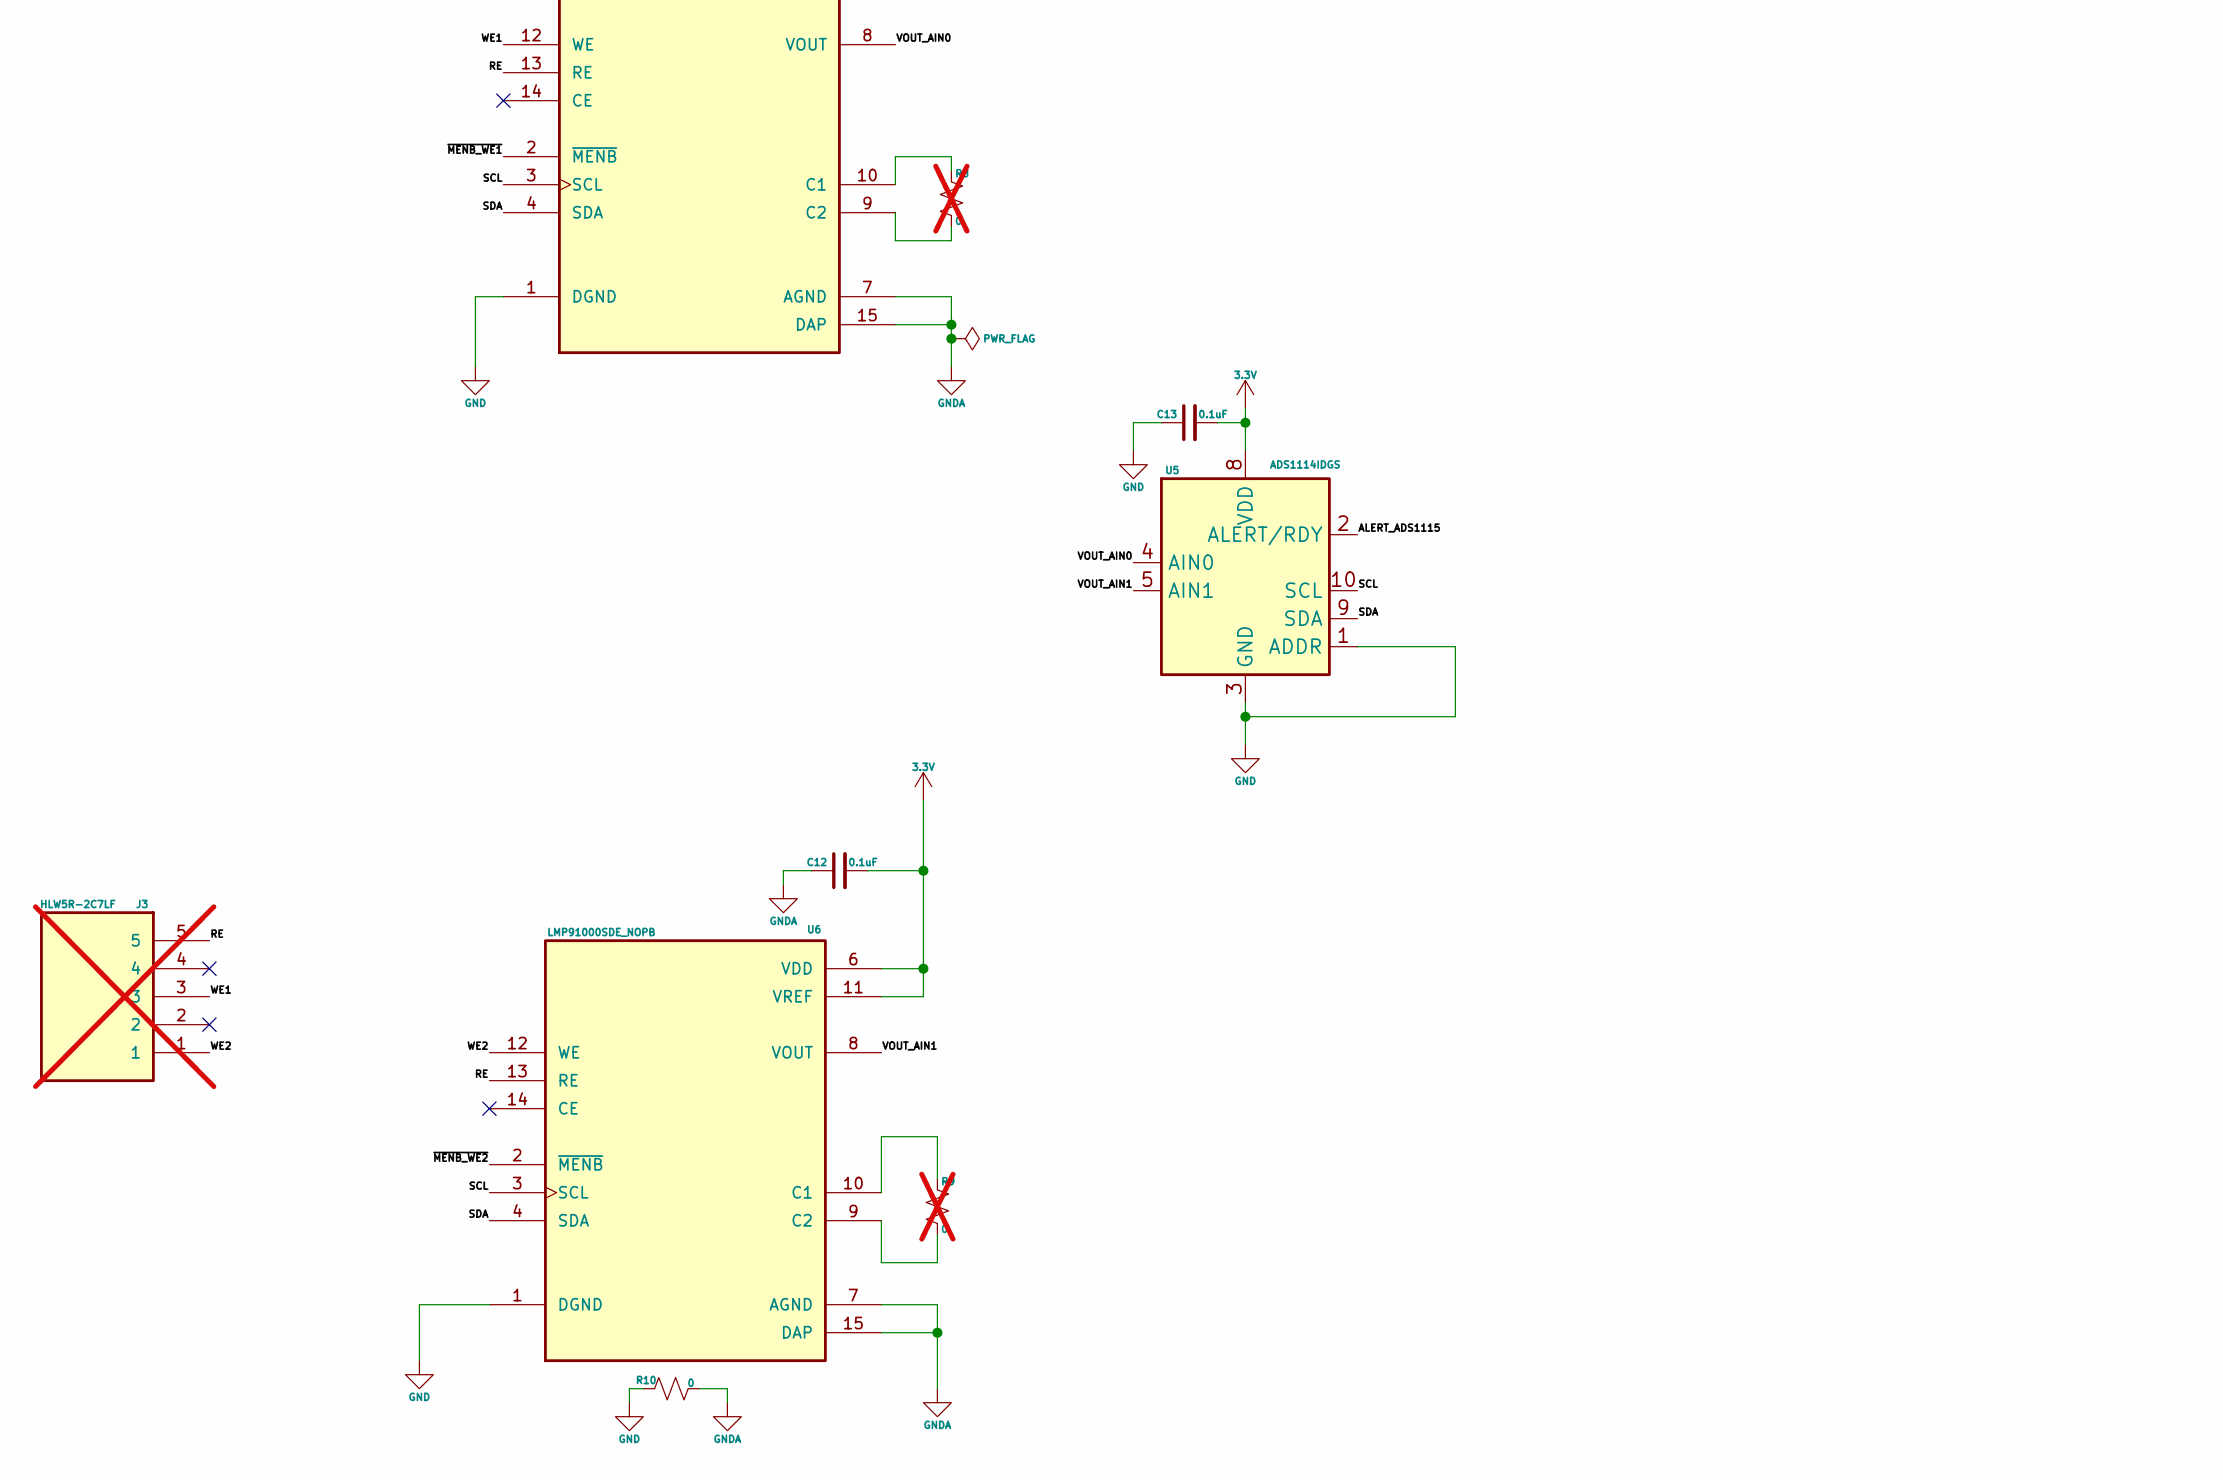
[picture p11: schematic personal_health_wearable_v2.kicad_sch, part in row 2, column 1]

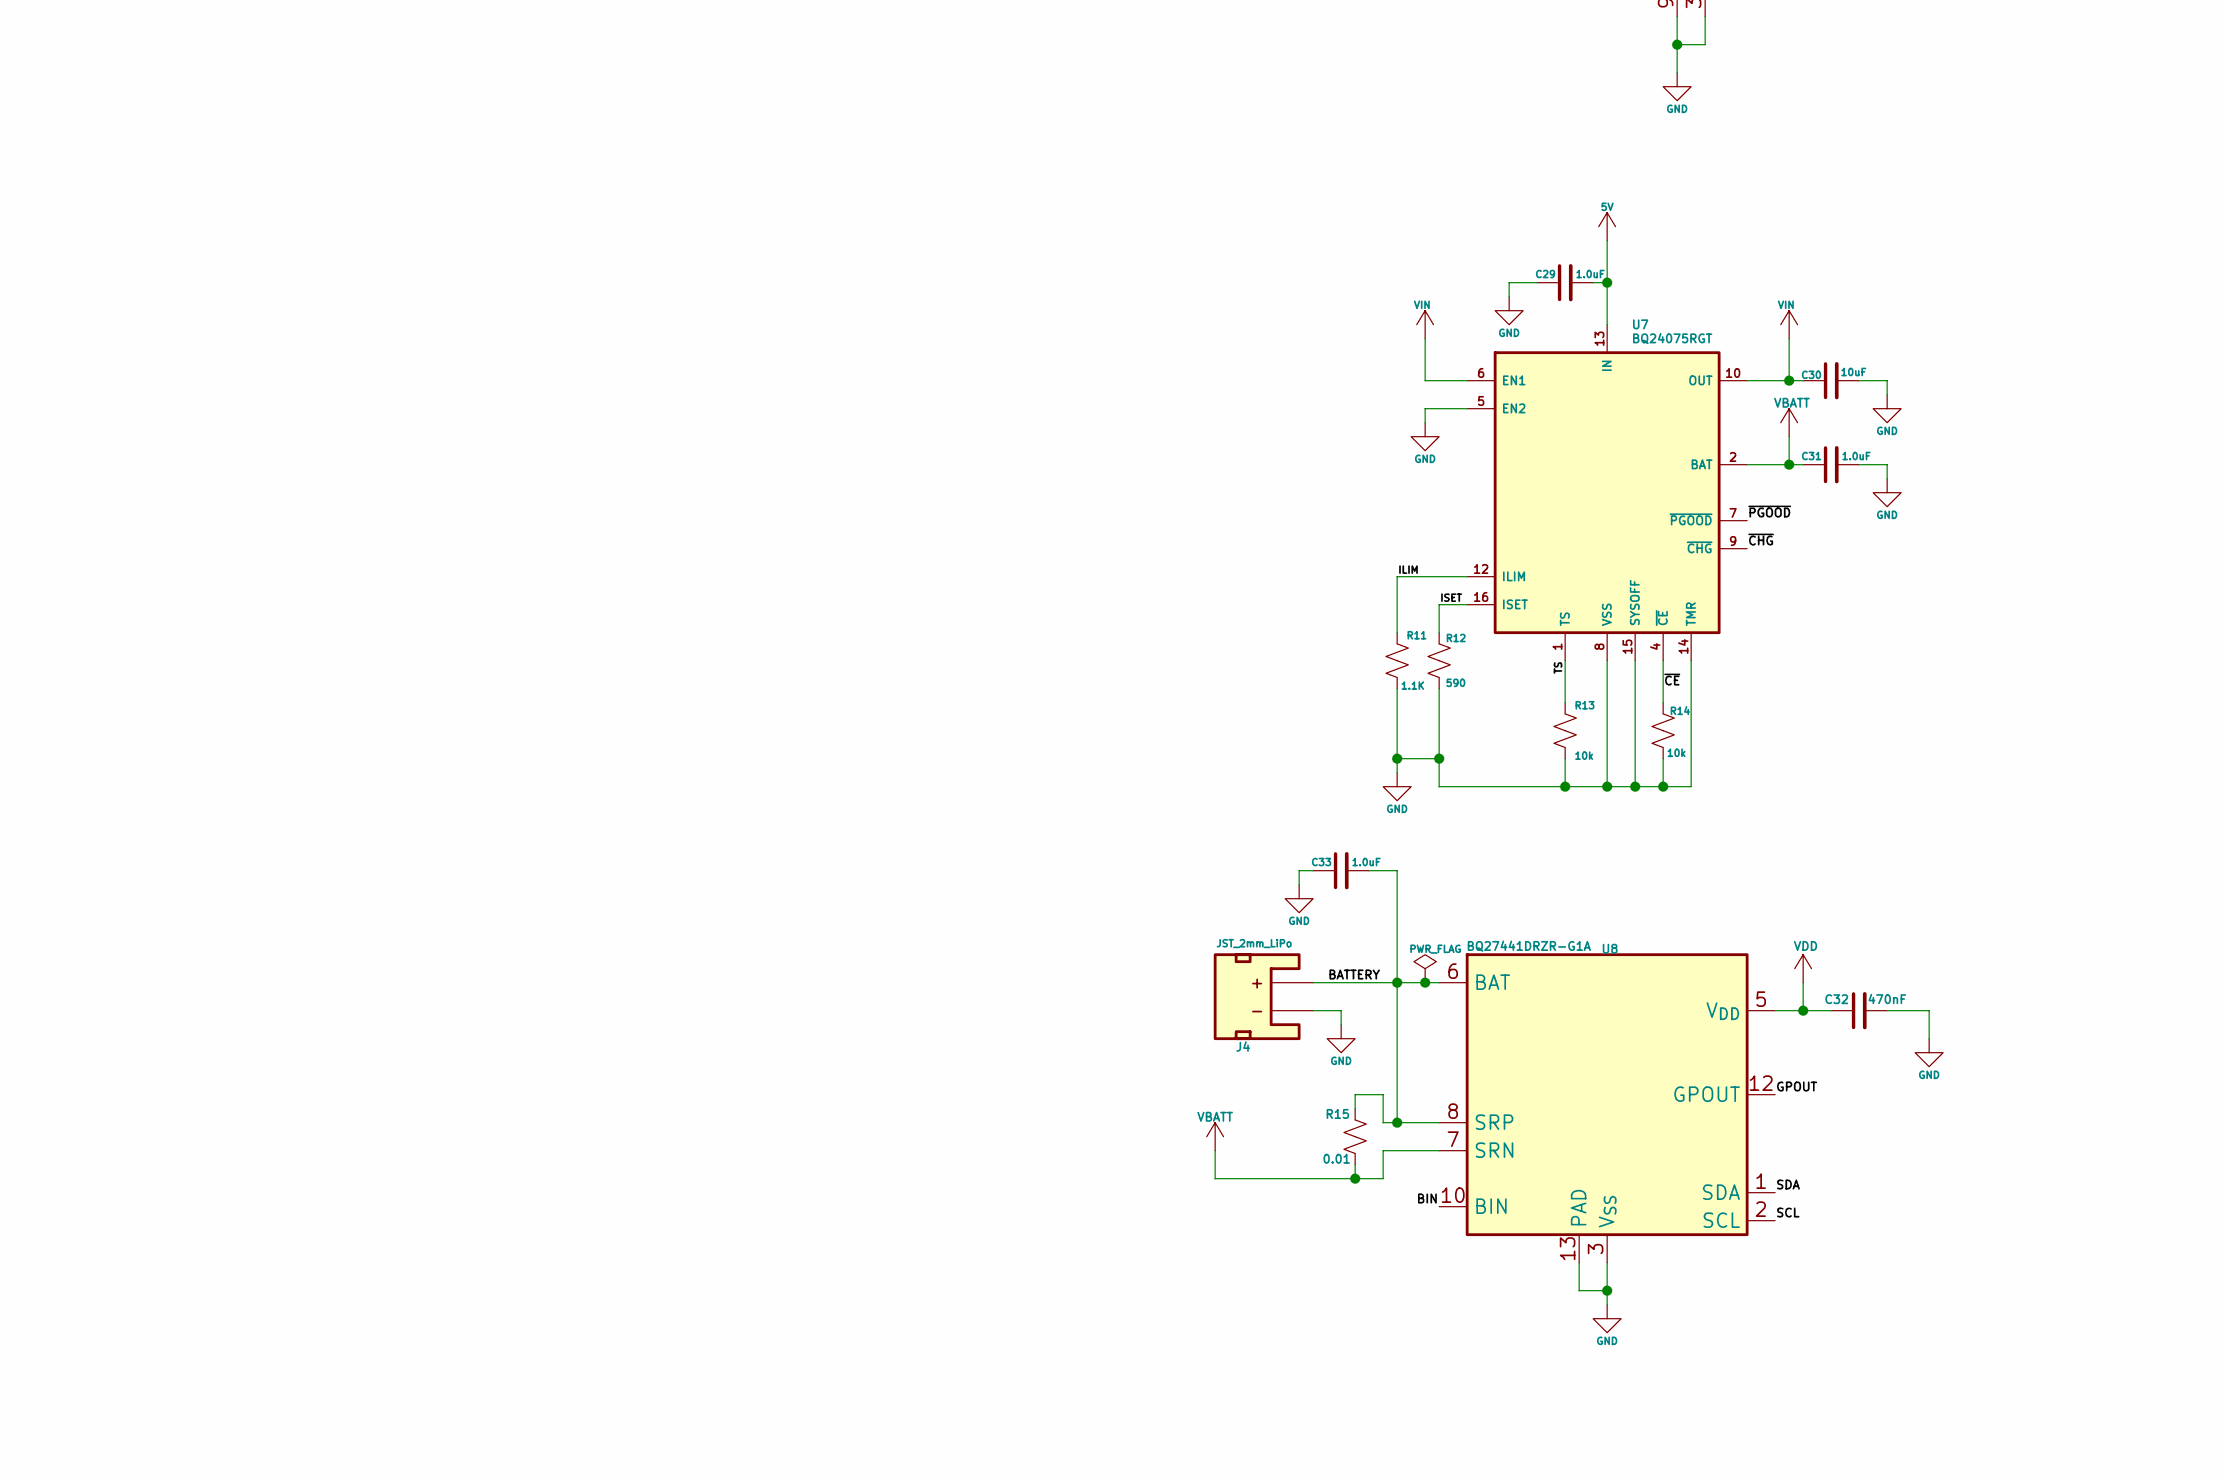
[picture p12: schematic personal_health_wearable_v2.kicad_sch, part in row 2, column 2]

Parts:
C1: 22uF; C_0402_1005Metric; Voltage 6.3V; Tolerance 20%; LCSC C105226
C2, C3, C4, C5, C6, C10, C11, C12, C13, C25: 0.1uF; C_0402_1005Metric; Voltage 6.3V; Tolerance 10%; LCSC C1525
C7, C8, C9, C30: 10uF; C_0402_1005Metric; Voltage 6.3V; Tolerance 20%; LCSC C15525
C14, C15, C16, C17, C18, C19, C20, C21, C22, C23, C24, C26, C29, C31, C33: 1.0uF; C_0402_1005Metric; Voltage 16V; Tolerance 10%; LCSC C361059
C27, C28: 2.2uF; C_0402_1005Metric; Voltage 10V; Tolerance 10%; LCSC C159814
C32: 470nF; C_0402_1005Metric; Voltage 6.3V; Tolerance 10%; LCSC C47339
CN1: FPC-SMD_30P-P0.50_FH12A-30S-0.5SH; Manufacturer Part FH12A-30S-0.5SH(55); LCSC C3036214
D1: Red; LED_0402_1005Metric_Red; LCSC C74341
D2: 350mA; D_SOD-523; LCSC C154768
J1: TYPE-C-31-M-12; HRO_TYPE-C-31-M-12; PARTREV 2020.12.08; LCSC C165948
J2: Conn_01x04_RA; 1x04_P2.54mm_Header_Horizontal_SMD; not fitted
J3: HLW5R-2C7LF; AMPHENOL_HLW5R-2C7LF; PARTREV C; DigiKey_Part_Number 609-1816-ND; not fitted
J4: JST_2mm_LiPo; JST_1x02_P2.0mm_Horizontal_SMD; LCSC C295747
JP1: Jumper_3_Open; Jumper_3_NO
L1: 2.2nH; L_0402_1005Metric; LCSC C27122
L2: LQH3NPN2R2MJRL; IND_LQH3NPN2R2MJRL; PARTREV N/A; LCSC C341775
R1, R2, R13, R14: 10k; R_0402_1005Metric; LCSC C25531
R3, R6: 100; R_0402_1005Metric; LCSC C25076
R4, R5: 5.1k; R_0402_1005Metric; LCSC C25905
R8, R9: 0; R_0402_1005Metric; not fitted
R10: 0; R_0402_1005Metric; LCSC C17168
R11: 1.1K; R_0402_1005Metric; LCSC C25860
R12: 590; R_0402_1005Metric; LCSC C159007
R15: 0.01; R_0402_1005Metric; LCSC C346478
SW1, SW2: SMD_4.6x2.8mm_h1.9mm; Push_SMD_4.6x2.8mm_h1.9mm; LCSC C99271
U1: ESP32-C6-MINI-1; LCSC C5736265
U3: TPS63001; Texas_DRC0010J_ThermalVias; LCSC C28060
U4, U6: LMP91000SDE_NOPB; SON50P400X400X80-15N; PARTREV DEC 2014; LCSC C181364
U5: ADS1114IDGS; TSSOP-10_3x3mm_P0.5mm; LCSC C174291
U7: BQ24075RGT; VQFN-16-1EP_3x3mm_P0.5mm_EP1.6x1.6mm; LCSC C15464
U8: BQ27441DRZR-G1A; Texas_S-PDSO-N12; LCSC C473397

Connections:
3.3V: C1.1, C2.1, C7.1, C8.1, C11.2, C12.2, C13.2, CN1.3 (VDD), J2.1, JP1.1 (A), R1.2, R2.2, U1.3 (3V3), U3.1 (VOUT), U3.10 (FB), U4.6 (VDD), U4.11 (VREF), U5.8 (VDD), U6.6 (VDD), U6.11 (VREF)
5V: C6.1, C29.2, L1.2, U7.13 (IN)
/ALERT_ADS1115: U1.10 (IO5), U5.2 (ALERT/RDY)
/BATTERY: C33.2, J4.2 (+), R15.2, U8.6 (BAT), U8.8 (SRP)
/BIN: U1.19 (IO14), U8.10 (BIN)
/BS: CN1.10 (BS), JP1.2 (C)
/BUSY: CN1.9 (BUSY), U1.29 (IO23)
/C1N: C27.1, CN1.26 (C1N)
/C1P: C27.2, CN1.27 (C1P)
/C2N: C16.1, CN1.24 (C2N)
/C2P: C16.2, CN1.25 (C2P)
/C3N: C17.2, CN1.22 (C3N)
/C3P: C17.1, CN1.23 (C3P)
/C4N: C18.2, CN1.20 (C4N)
/C4P: C18.1, CN1.21 (C4P)
/C5N: C19.2, CN1.18 (C5N)
/C5P: C19.1, CN1.19 (C5P)
/C6N: C20.2, CN1.16 (C6N)
/C6P: C20.1, CN1.17 (C6P)
/CC1: J1.A5 (CC1), R4.2
/CC2: J1.B5 (CC2), R5.1
/CLK: CN1.5 (CLK), U1.27 (IO21)
/CS: CN1.6 (CS), U1.24 (IO18)
/DC: CN1.7 (DC), U1.25 (IO19)
/DIN: CN1.4 (DIN), U1.28 (IO22)
/ESP32.RX: J2.3, U1.30 (RXD0)
/ESP32.TX: J2.2, U1.31 (TXD0)
/GPIO0: R3.2, U1.12 (IO0)
/GPOUT: U1.20 (IO15), U8.12 (GPOUT)
/ILIM: R11.2, U7.12 (ILIM)
/IO8: R2.1, U1.22 (IO8)
/ISET: R12.2, U7.16 (ISET)
/L1: L2.1, U3.4 (L1)
/L2: L2.2, U3.2 (L2)
/LED: D1.2 (A), R3.1
/RE: J3.5, U4.13 (RE), U6.13 (RE)
/RST: CN1.8 (RST), U1.26 (IO20)
/SCL: U1.5 (IO2), U4.3 (SCL), U5.10 (SCL), U6.3 (SCL), U8.2 (SCL)
/SDA: U1.6 (IO3), U4.4 (SDA), U5.9 (SDA), U6.4 (SDA), U8.1 (SDA)
/TS: R13.2, U7.1 (TS)
/USBC.D+: J1.A6 (DP1), J1.B6 (DP2), U1.18 (IO13)
/USBC.D-: J1.A7 (DN1), J1.B7 (DN2), U1.17 (IO12)
/VCOM: C14.2, CN1.30 (VCOM)
/VCOMH: C28.2, CN1.29 (VCOMH)
/VCOML: C15.2, CN1.28 (VCOML)
/VDDD: C24.2, C25.2, CN1.11 (VDDD)
/VDH: C22.2, CN1.13 (VDH)
/VDL: C21.2, CN1.12 (VDL)
/VGH: C23.2, CN1.14 (VGH)
/VGL: C26.2, CN1.15 (VGL), D2.2 (A)
/VINA: C10.1, R6.2, U3.6 (EN), U3.7 (PS/SYNC), U3.8 (VINA)
/VOUT_AIN0: U4.8 (VOUT), U5.4 (AIN0)
/VOUT_AIN1: U5.5 (AIN1), U6.8 (VOUT)
/WE1: J3.3, U4.12 (WE)
/WE2: J3.1, U6.12 (WE)
/~BOOT: SW2.2, U1.23 (IO9)
/~CE: R14.2, U7.4 (~CE)
/~CHG: U1.16 (IO7), U7.9 (~CHG)
/~MENB_WE1: U1.13 (IO1), U4.2 (~MENB)
/~MENB_WE2: U1.9 (IO4), U6.2 (~MENB)
/~PGOOD: U1.15 (IO6), U7.7 (~PGOOD)
/~RESET: C3.1, C4.2, R1.1, SW1.2, U1.8 (EN)
GND: C1.2, C2.2, C3.2, C4.1, C5.2, C6.2, C7.2, C8.2, C9.2, C10.2, C13.1, C14.1, C15.1, C21.1, C22.1, C23.1, C24.1, C25.1, C26.1, C28.1, C29.1, C30.2, C31.2, C32.2, C33.1, CN1.2 (GND), CN1.31 (GND), CN1.32 (GND), D1.1 (K), D2.1 (K), J1.A1_B12 (GND), J1.B1_A12 (GND__1), J1.S1 (SHIELD), J1.S2 (SHIELD__1), J1.S3 (SHIELD__2), J1.S4 (SHIELD__3), J2.4, J4.1 (-), JP1.3 (B), R4.1, R5.2, R10.1, R11.1, R12.1, R13.1, R14.1, SW1.1, SW2.1, U1.1 (GND), U1.2 (GND), U1.11 (GND), U1.14 (GND), U1.36 (GND), U1.37 (GND), U1.38 (GND), U1.39 (GND), U1.40 (GND), U1.41 (GND), U1.42 (GND), U1.43 (GND), U1.44 (GND), U1.45 (GND), U1.46 (GND), U1.47 (GND), U1.48 (GND), U1.49 (GND), U1.50 (GND), U1.51 (GND), U1.52 (GND), U1.53 (GND), U3.3 (PGND), U3.9 (GND), U3.11 (PGND), U4.1 (DGND), U5.1 (ADDR), U5.3 (GND), U6.1 (DGND), U7.5 (EN2), U7.8 (VSS), U7.14 (TMR), U7.15 (SYSOFF), U7.17 (VSS), U8.3 (V_{SS}), U8.13 (PAD)
GNDA: C11.1, C12.1, R10.2, U4.7 (AGND), U4.15 (DAP), U6.7 (AGND), U6.15 (DAP)
unnamed: R8.2, U4.10 (C1)
unnamed: R8.1, U4.9 (C2)
unnamed: R9.2, U6.10 (C1)
unnamed: R9.1, U6.9 (C2)
VBATT: C31.1, R15.1, U7.2 (BAT), U7.3 (BAT), U8.7 (SRN)
VDD: C32.1, U8.5 (V_{DD})
VIN: C9.1, C30.1, R6.1, U3.5 (VIN), U7.6 (EN1), U7.10 (OUT), U7.11 (OUT)
VUSB: C5.1, J1.A4_B9 (VBUS), J1.B4_A9 (VBUS__1), L1.1

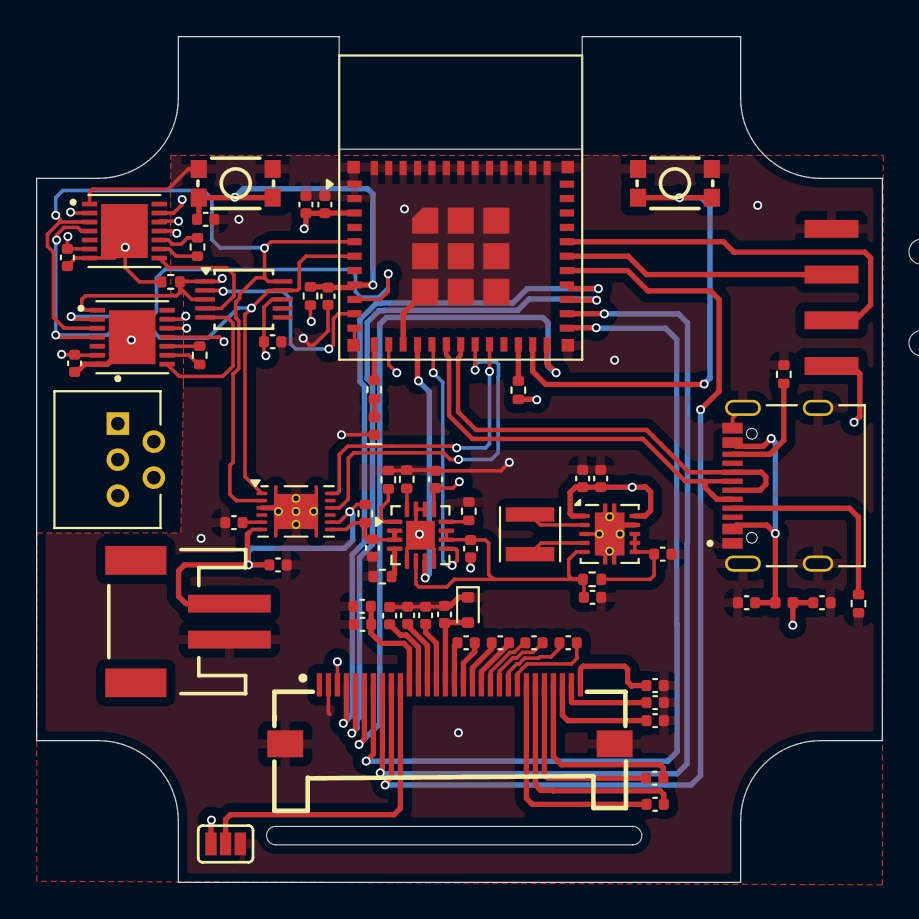
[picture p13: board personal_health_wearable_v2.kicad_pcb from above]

Board: 4 copper layers, 47.0 x 47.0 mm, 66 parts (0 on the bottom side), 72 nets.

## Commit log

2025-01-26 Design file check-in
    [Personal_Health_Monitoring_Wearable.f3z, comprehensive_personal_health_wearable.f3z]
2025-03-20 Create ElectronicsDesign_BL5415 v2.f3z
    [ElectronicsDesign_BL5415 v2.f3z]
2025-03-24 Update ElectronicsDesign_BL5415 v2.f3z
    [ElectronicsDesign_BL5415 v2.f3z]
2025-03-28 Create ElectronicsDesign_BL5415 v28.f3z
    [ElectronicsDesign_BL5415 v28.f3z]
2025-05-07 organizing design files
    [BoM_Kitchen_Sink_Wearable.xlsx, ElectronicsDesign_BL5415 v2.f3z, ElectronicsDesign_BL5415 v28.f3z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]
2026-03-15 Checking in v2 of wearable.
    [personal_health_wearable_v2.kicad_pcb, personal_health_wearable_v2.kicad_sch]
2026-03-20 Routed i2c connections
    [personal_health_wearable_v2.kicad_sch]
2026-03-26 Completed schematic
    [personal_health_wearable_v2.kicad_pcb]
2026-03-28 Completed design file, BoM, and Gerbers
    [bom.csv, designators.csv, personal_health_wearable_v2.kicad_pcb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]
